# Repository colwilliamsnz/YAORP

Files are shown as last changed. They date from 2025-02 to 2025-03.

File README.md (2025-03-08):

# YAORP (Yet Another Open Reflow Plate)

## Status:

Tested an initial v1.0 board. Various improvements and bug fixes applied to produce rev 1.2 (build pending). Basic PoC firmware written.

## Introduction:

A design for a solder reflow plate for SMD rework using commonly available aluminium 240V AC 400W PTC (positive temperature coefficient) heating plate from AliExpress.

PTC temperature is determined using an infrared thermometer (MLX90614). The PTC is driven by an SSR (solid state relay) using PWM (pulse width modulation), and controlled by a PID (proportional integral derivative).

An ESP32 S3 Wroom 1 module forms the heart of the design and firmware is written in C++ for Arduino IDE. 

Two PCBs have been designed using KiCAD 9. The main controller board (board 1) and a cooling plate/heat dissipator (board 2).

## Project Goals:

- Enhance my knowledge of electronics. 
- Learn KiCad.
- Make the move away from hand soldered components.
- Build a useful addition to my lab.
- Make it as professional as possible.

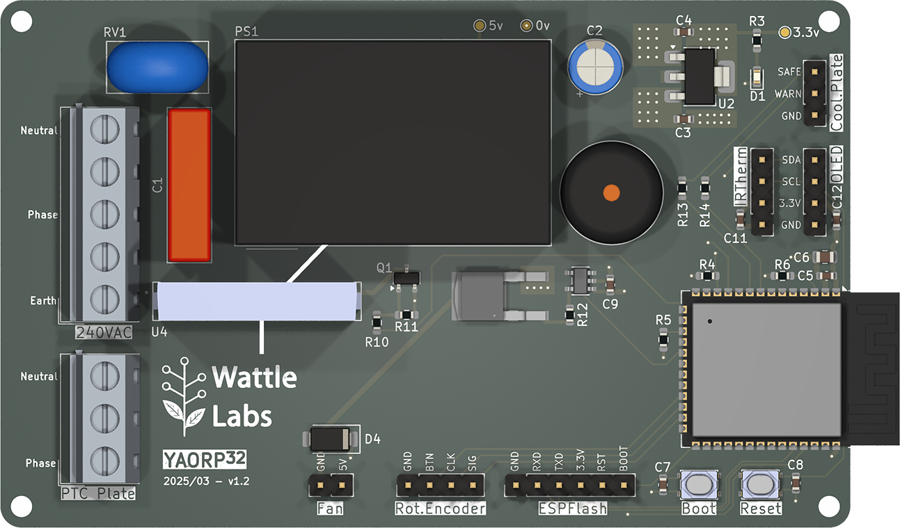
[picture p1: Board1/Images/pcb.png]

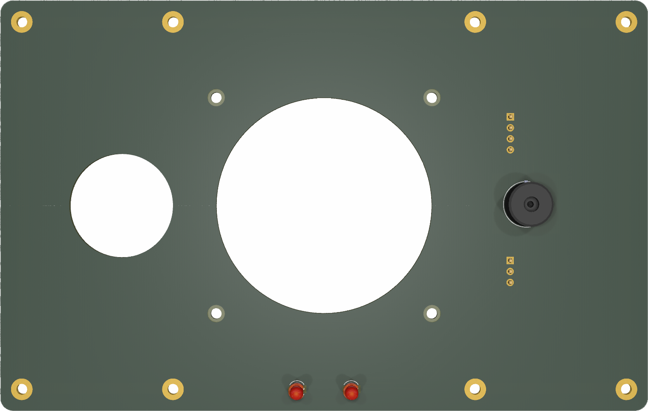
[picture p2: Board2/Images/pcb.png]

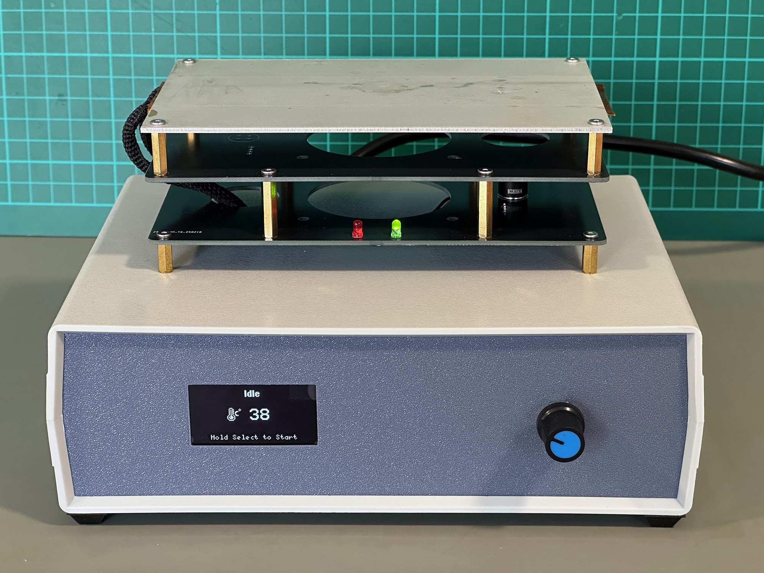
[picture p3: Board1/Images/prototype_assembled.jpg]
Prototype

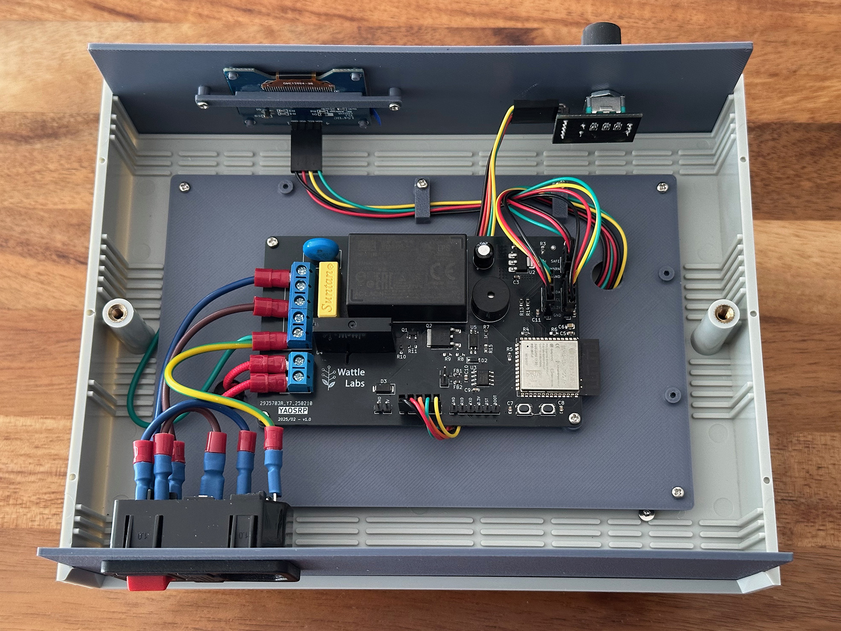
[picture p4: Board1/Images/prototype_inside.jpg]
Prototype


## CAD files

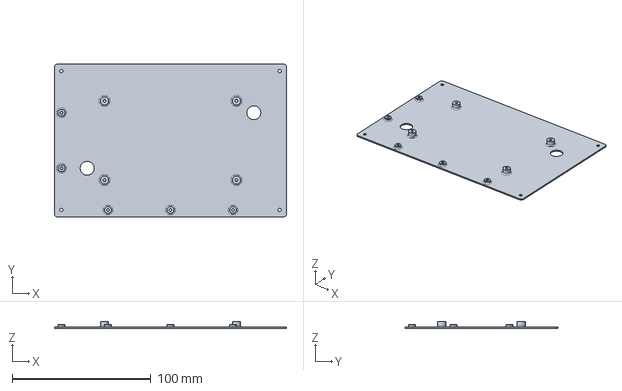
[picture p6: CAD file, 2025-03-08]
Board1/CAD/Case Mount.FCStd
167.0 x 110.0 x 5.00 mm

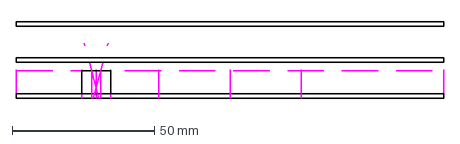
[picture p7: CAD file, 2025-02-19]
Board2/CAD/Cooling Plate 30deg Calc.dxf
150.0 x 26.8 mm

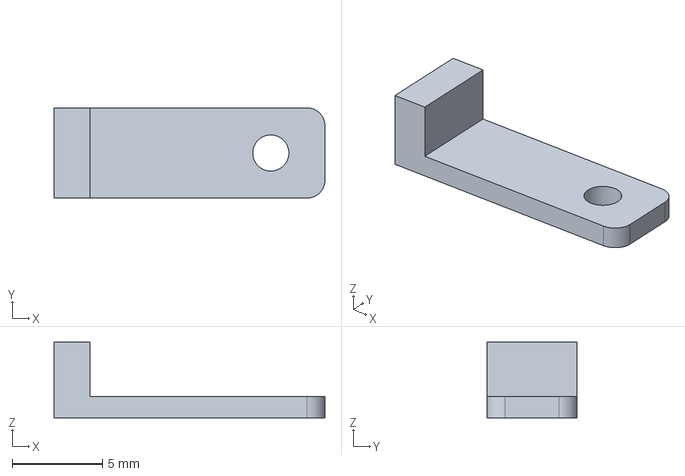
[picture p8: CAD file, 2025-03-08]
Board1/CAD/Cable Clips.FCStd
15.0 x 5.00 x 4.20 mm

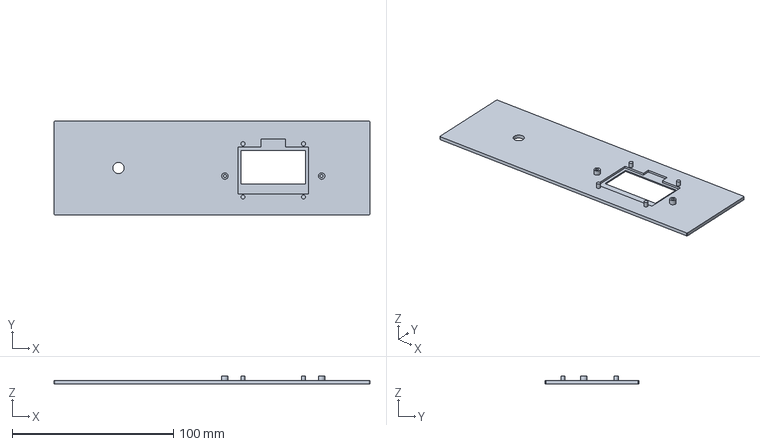
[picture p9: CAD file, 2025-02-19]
Board1/CAD/Front Panel.FCStd
196.0 x 58.0 x 5.15 mm

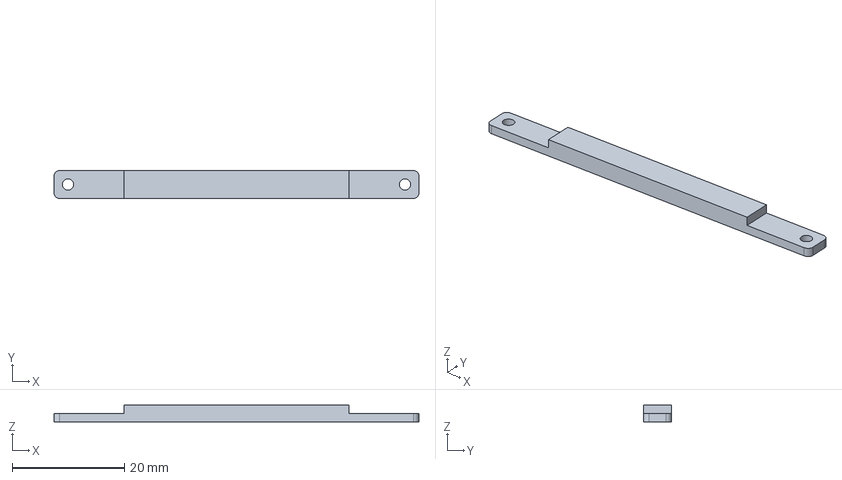
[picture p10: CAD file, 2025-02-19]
Board1/CAD/Screen Backplate.FCStd
65.0 x 5.00 x 3.00 mm

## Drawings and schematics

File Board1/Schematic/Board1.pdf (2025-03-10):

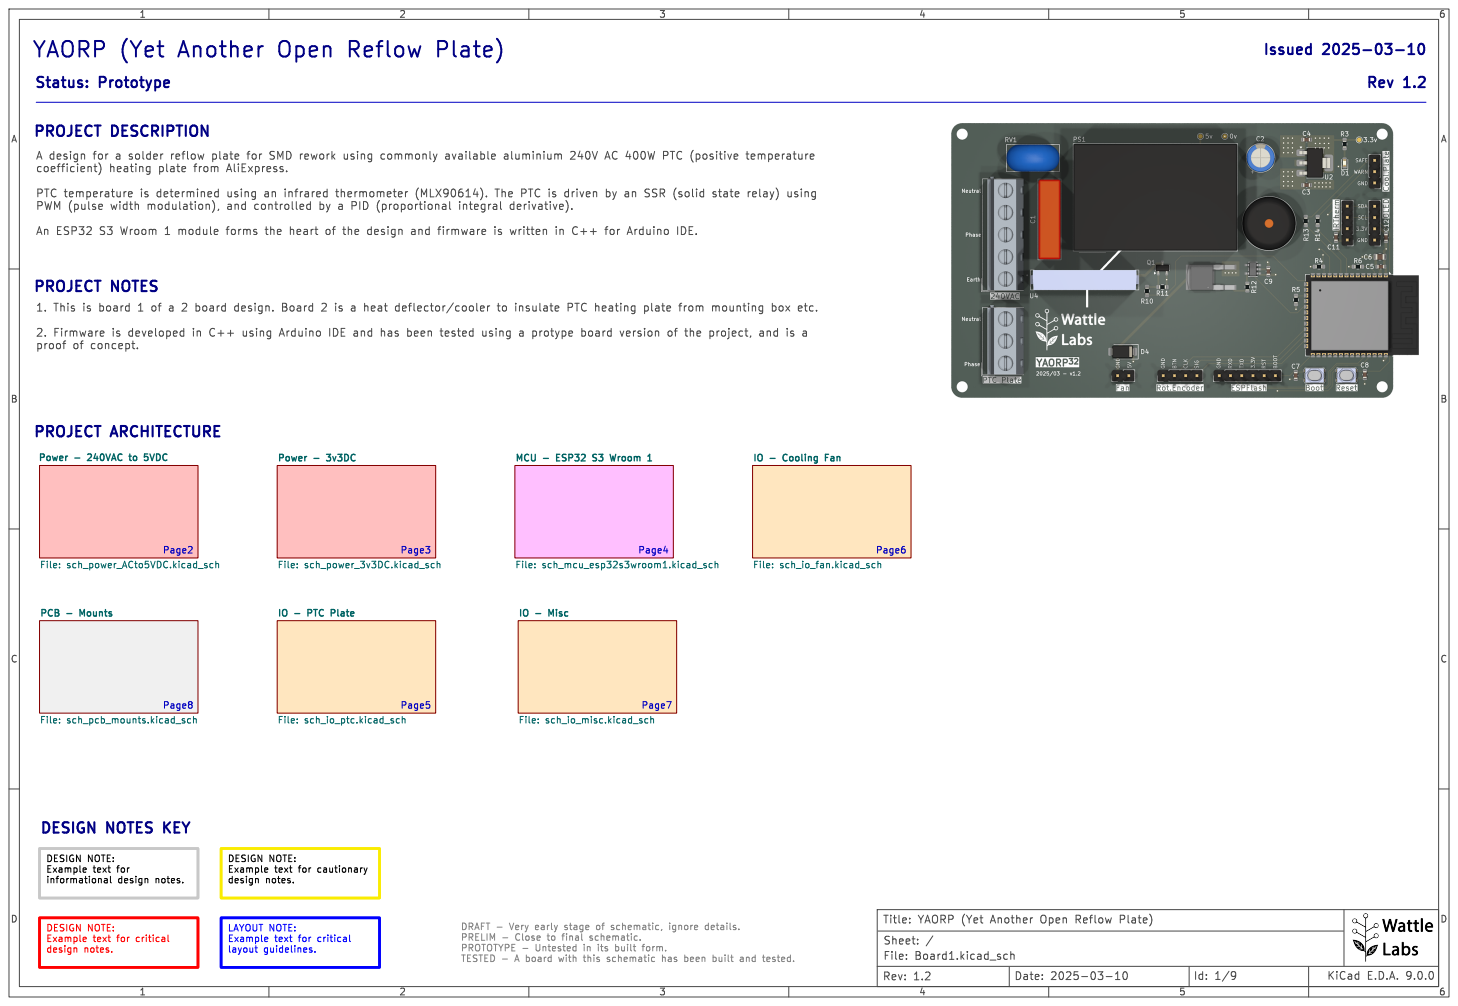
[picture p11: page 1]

IO - Misc File: sch_io_misc.kicad_sch Power - 240VAC to 5VDC

IO - PTC Plate File: sch_io_ptc.kicad_sch PCB - Mounts File: sch_pcb_mounts.kicad_sch

design notes. DESIGN NOTE: Example text for

layout guidelines. DESIGN NOTE: Example text for cautionary

LAYOUT NOTE: Example text for critical

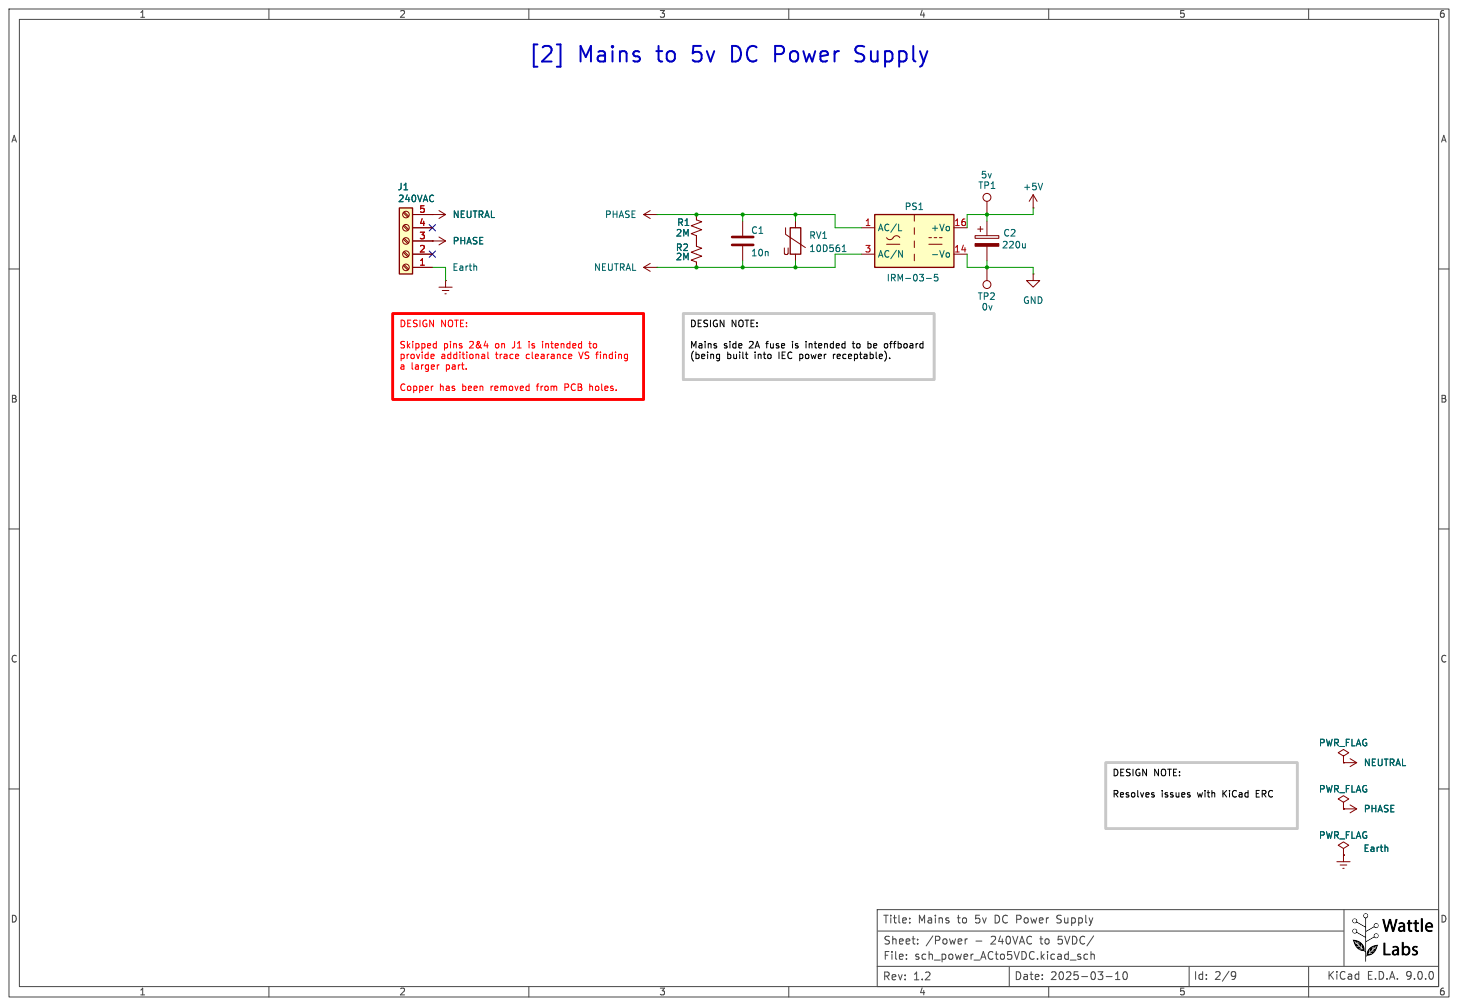
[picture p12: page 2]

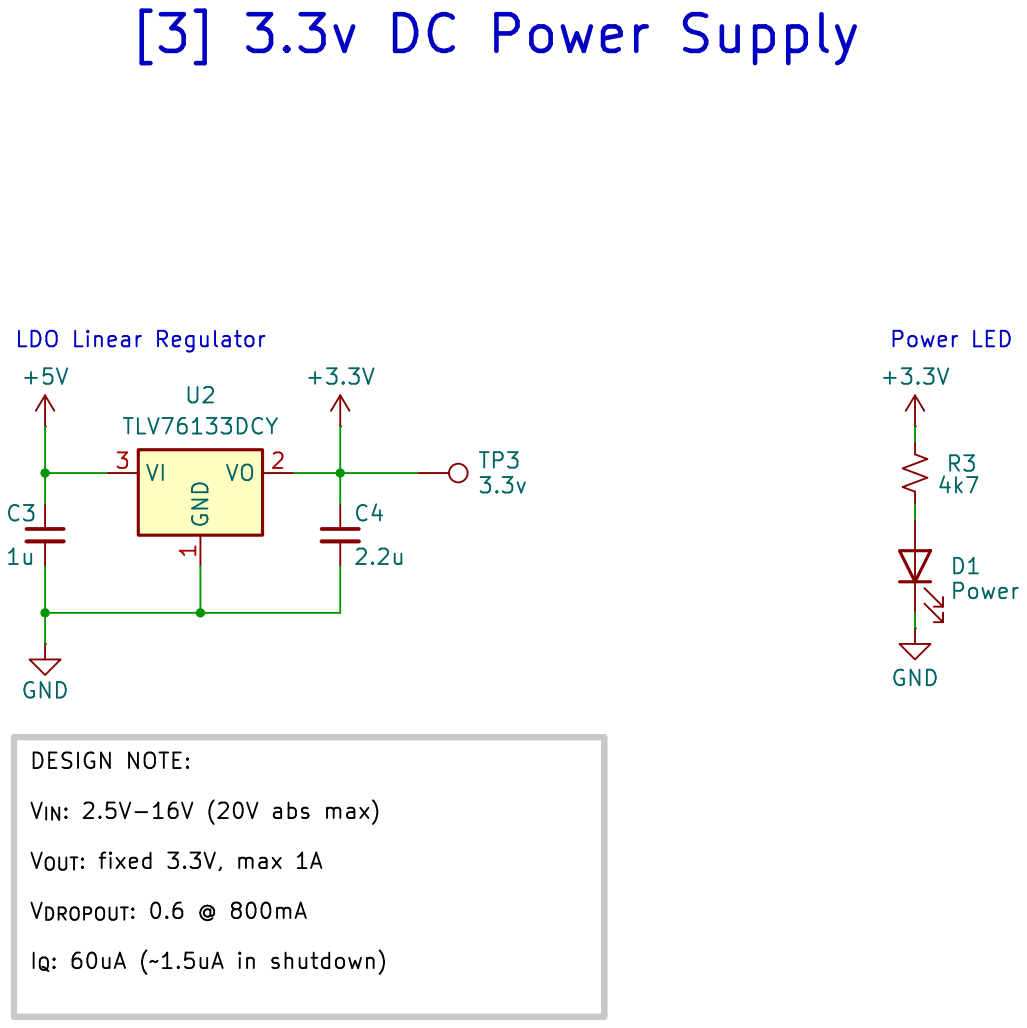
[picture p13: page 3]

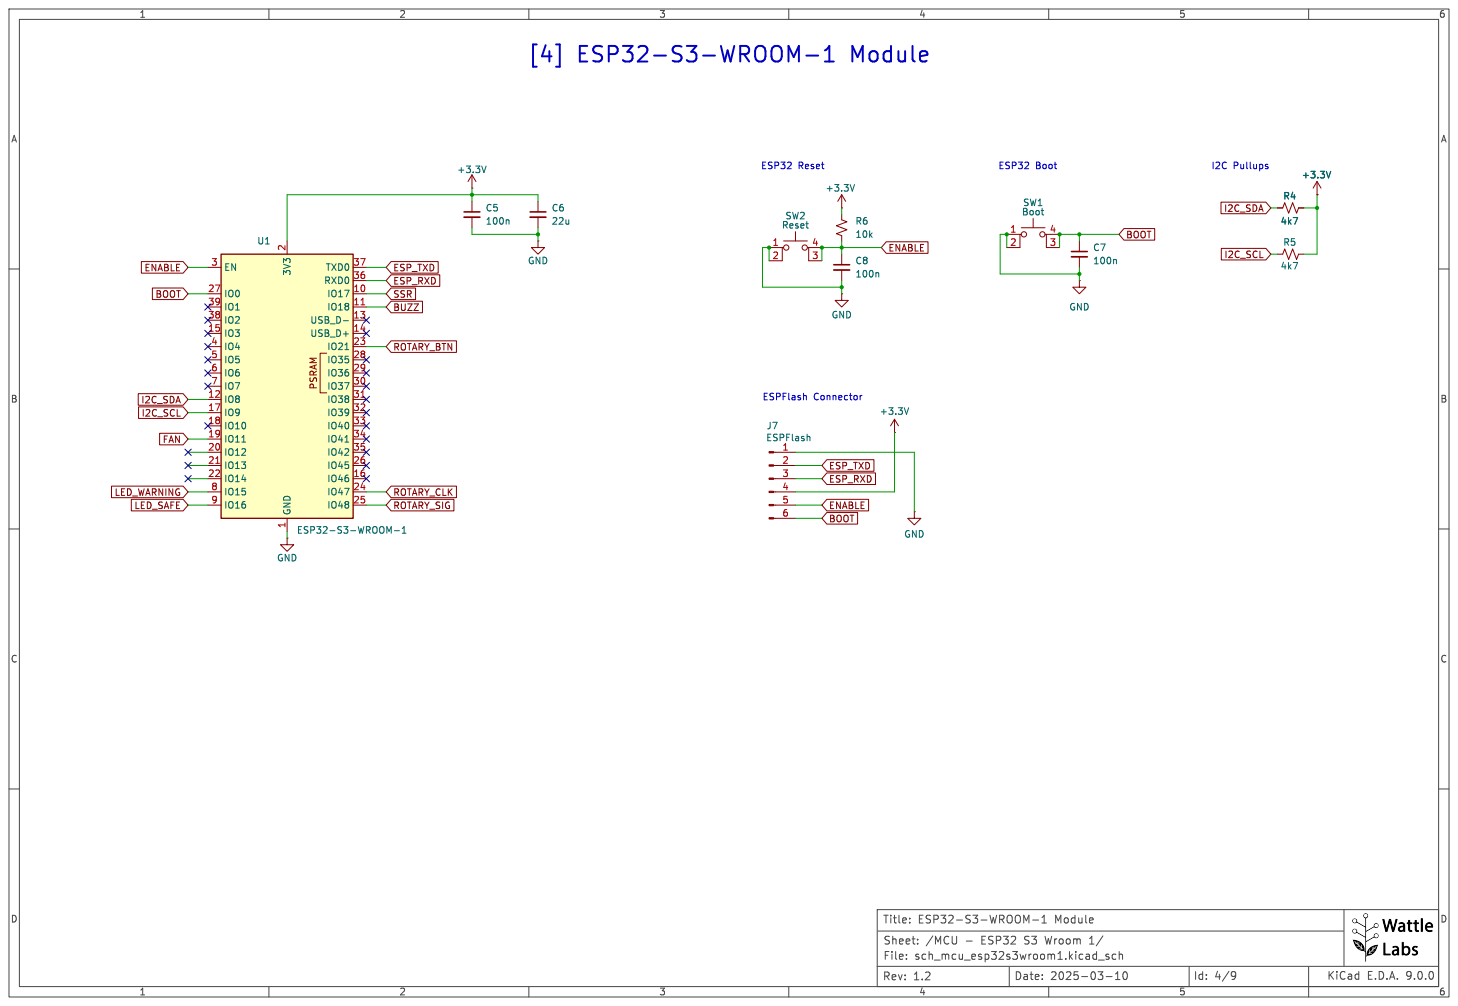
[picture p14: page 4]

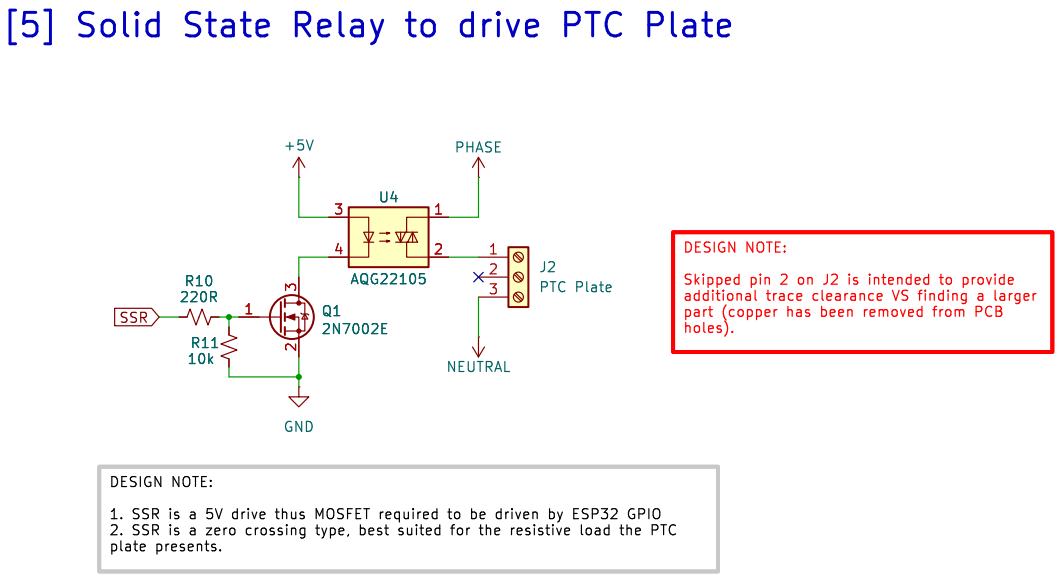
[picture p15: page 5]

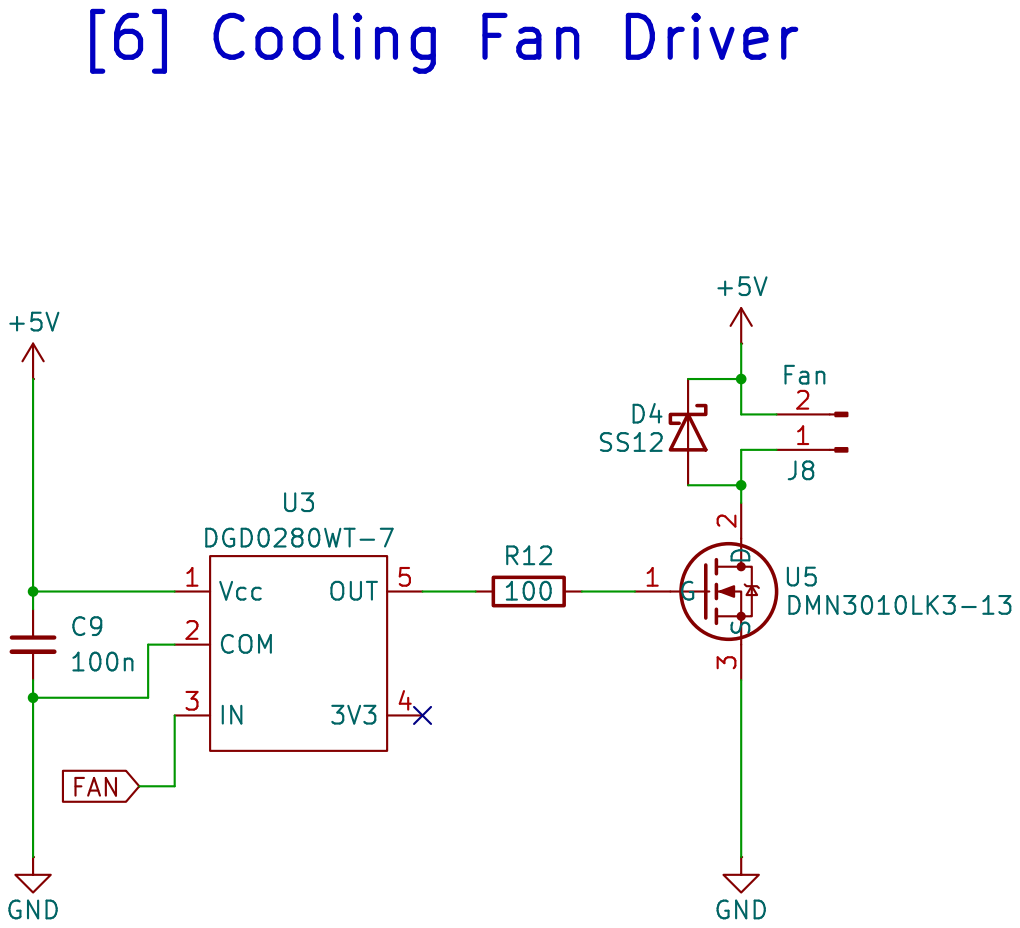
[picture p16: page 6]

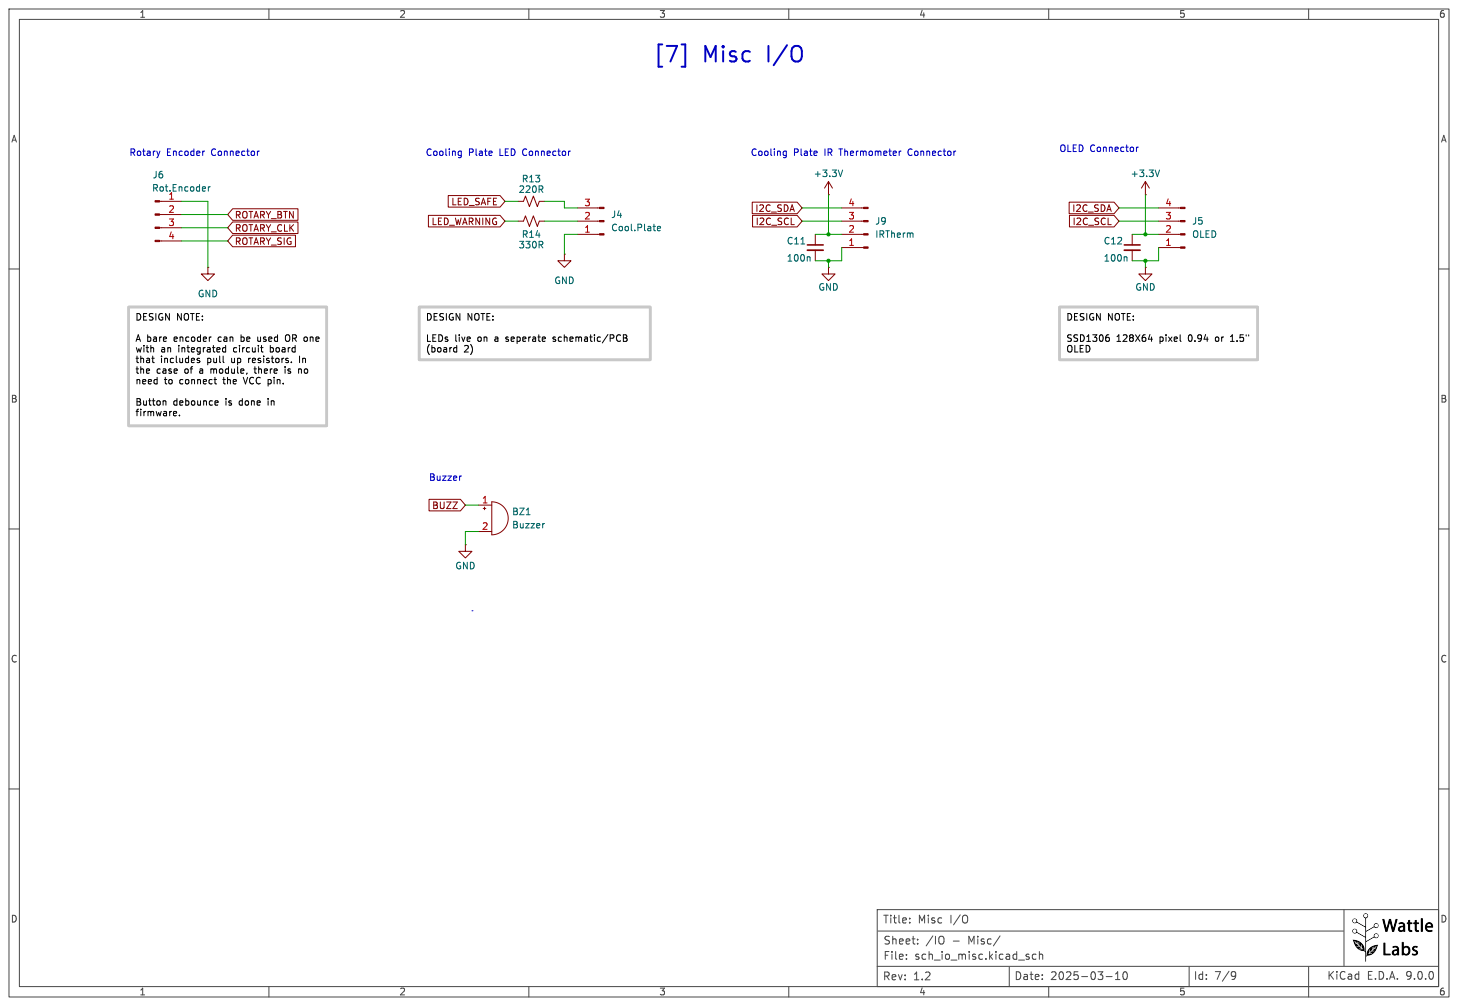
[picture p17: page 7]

DESIGN NOTE: LEDs live on a seperate schematic/PCB

the case of a module, there is no
need to connect the VCC pin. Button debounce is done in

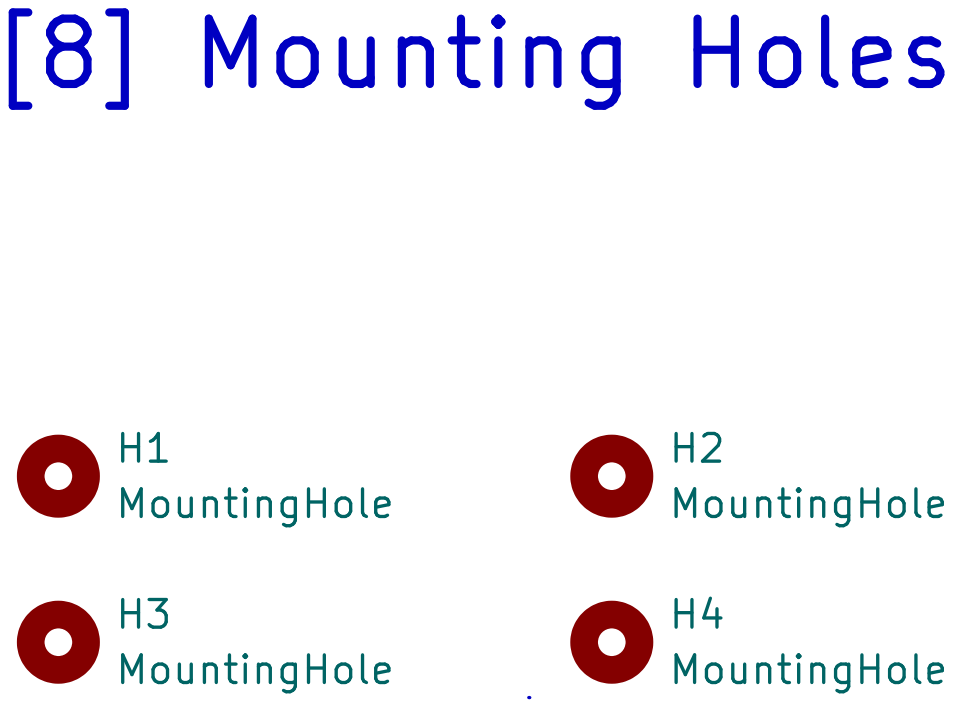
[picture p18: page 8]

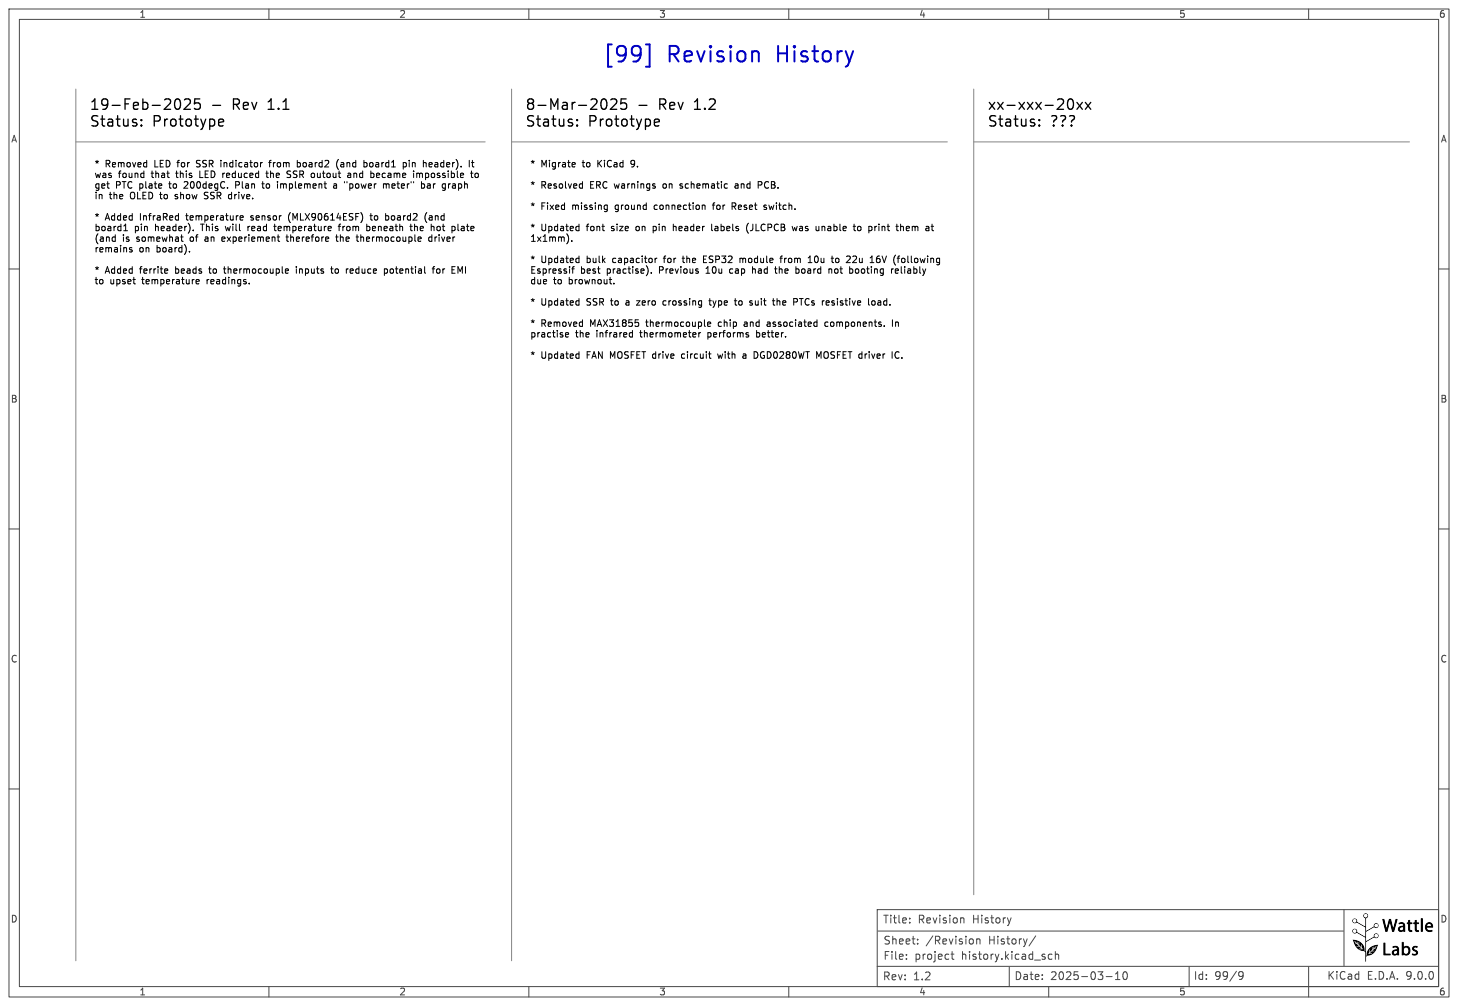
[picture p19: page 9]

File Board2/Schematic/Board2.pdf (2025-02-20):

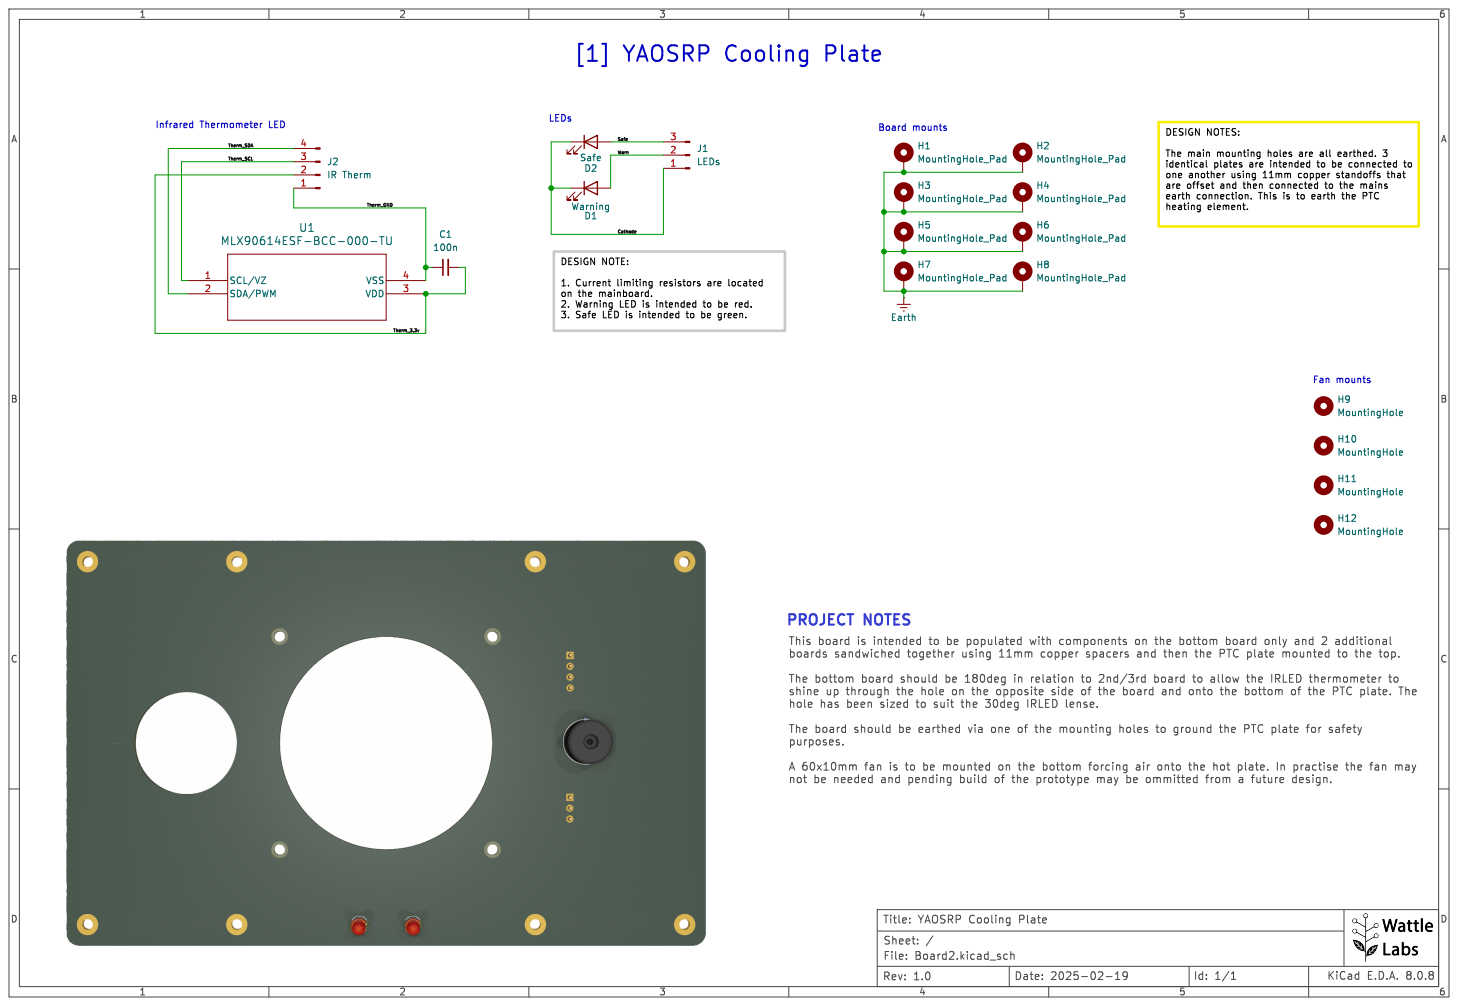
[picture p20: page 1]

shine up through the hole on the opposite side of the board and onto the bottom of the PTC plate. The

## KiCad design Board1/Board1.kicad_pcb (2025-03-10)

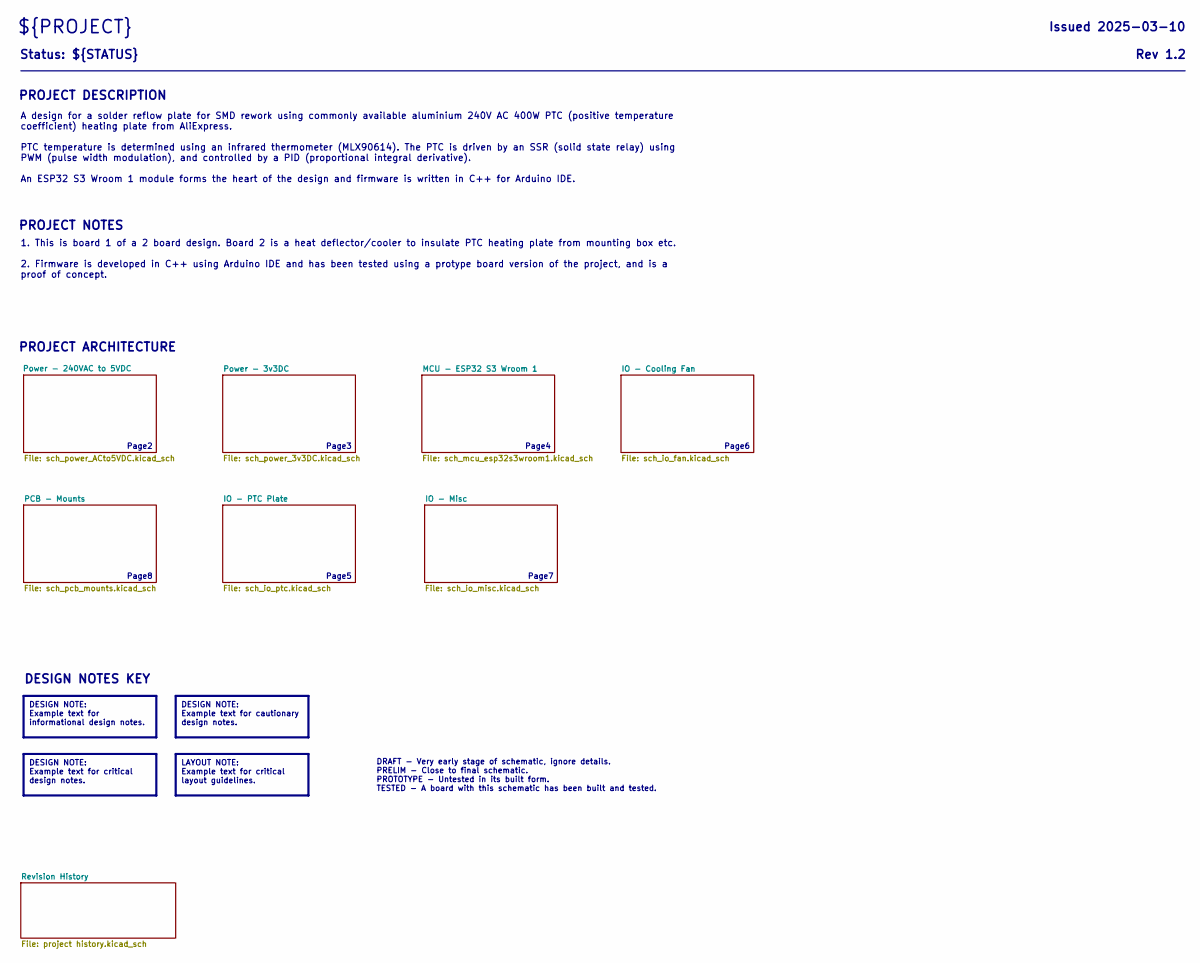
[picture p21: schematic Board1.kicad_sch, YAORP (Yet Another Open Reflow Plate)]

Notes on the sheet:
Page3
PROJECT DESCRIPTION
PROJECT NOTES
Page6
Page7
DESIGN NOTES KEY
PROJECT ARCHITECTURE
Page2
Page8
Page4
Page5
DESIGN NOTE: Example text for critical design notes.
DESIGN NOTE: Example text for informational design notes.
DESIGN NOTE: Example text for cautionary design notes.
Status: ${STATUS}
DRAFT - Very early stage of schematic, ignore details. PRELIM - Close to final schematic. PROTOTYPE - Untested in its built form. TESTED - A board with this schematic has been built and tested.
1. This is board 1 of a 2 board design. Board 2 is a heat deflector/cooler to insulate PTC heating plate from mounting box etc. 2. Firmware is developed in C++ using Arduino IDE and has been tested using a protype board version of the project, and is a proof of concept.
Rev ${REVISION}
A design for a solder reflow plate for SMD rework using commonly available aluminium 240V AC 400W PTC (positive temperature coefficient) heating plate from AliExpress. PTC temperature is determined using an infrared thermometer (MLX90614). The PTC is driven by an SSR (solid state relay) using PWM (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
${PROJECT}
LAYOUT NOTE: Example text for critical layout guidelines.
Issued ${ISSUE_DATE}

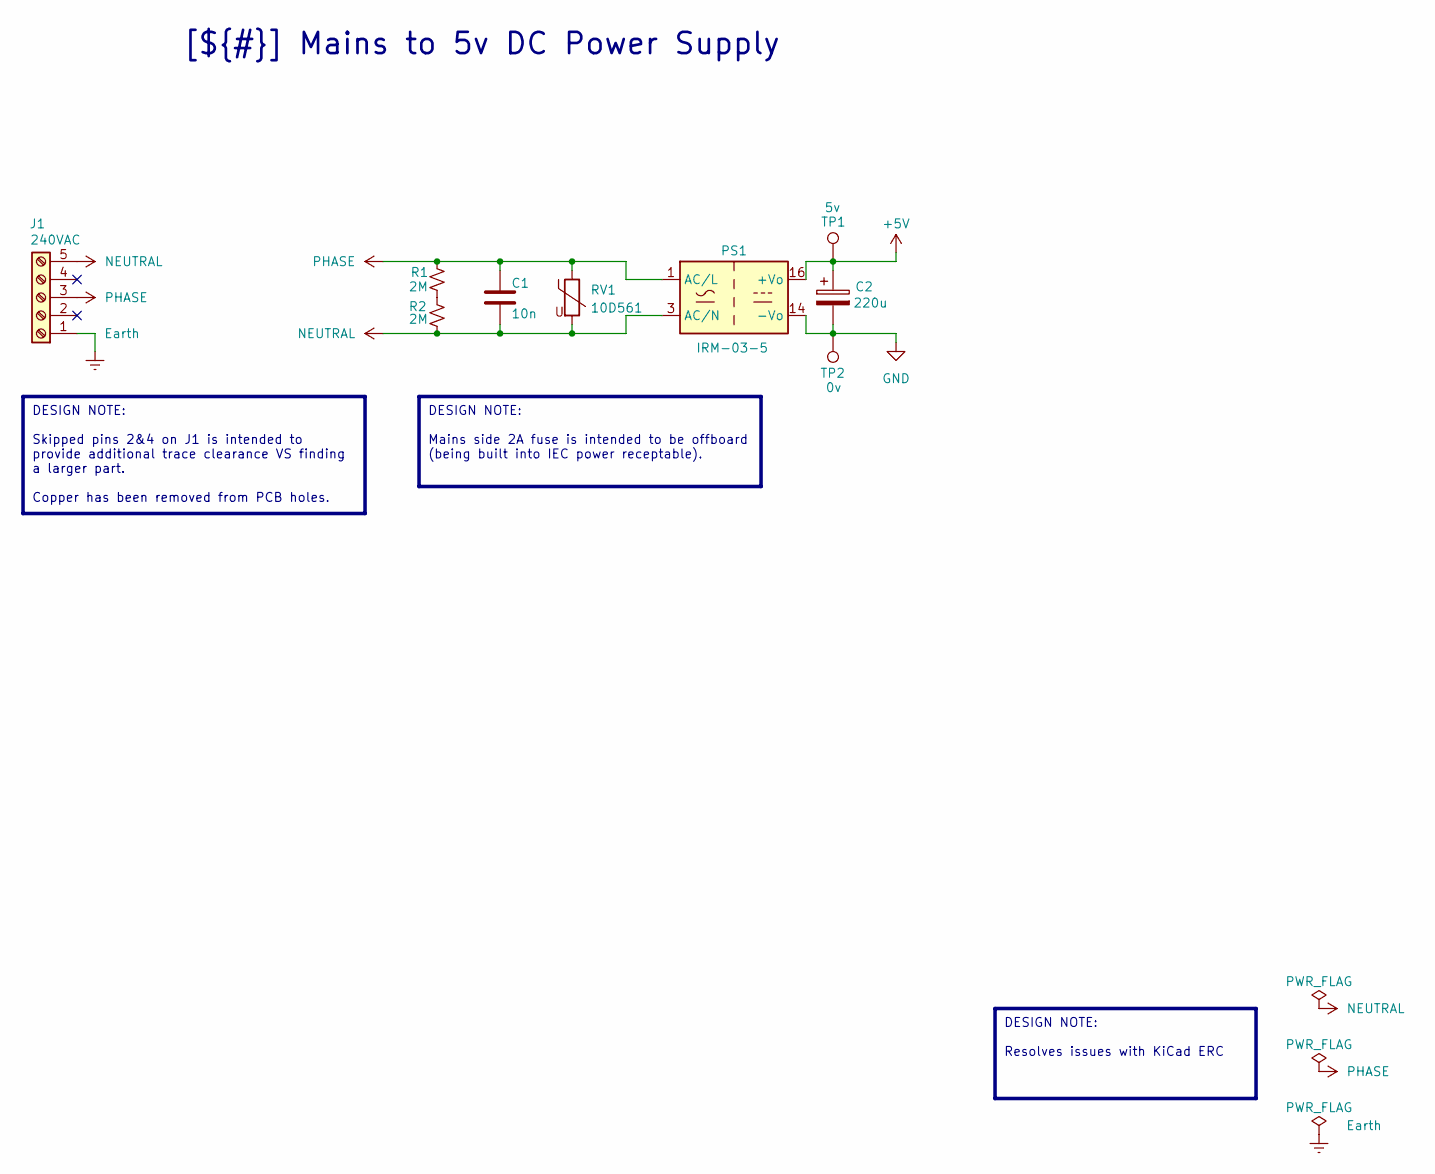
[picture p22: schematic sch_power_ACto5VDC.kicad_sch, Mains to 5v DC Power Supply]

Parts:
C1: 10n; C_Rect_L18.0mm_W5.0mm_P15.00mm_FKS3_FKP3; Digikey_PN BFC233841103-ND
C2: 220u; CP_Radial_D6.3mm_P2.50mm
J1: 240VAC; Altech_AK100_1x05_P5.00mm
PS1: IRM-03-5; Converter_ACDC_MeanWell_IRM-03-xx_THT; Digikey_PN 1866-3020-ND
R1, R2: 2M; R_2010_5025Metric_Pad1.40x2.65mm_HandSolder; Digikey_PN 2019-HV732HTTE2004FCT-ND
RV1: 10D561; RV_Disc_D12mm_W6.1mm_P7.5mm; Digikey_PN 118-MOV-10D561K-ND
TP1: 5v; TestPoint_Pad_D1.0mm
TP2: 0v; TestPoint_Pad_D1.0mm

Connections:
+5V: C2.1, PS1.16 (+Vo), TP1.1; also elsewhere on the board
GND: C2.2, PS1.14 (-Vo), TP2.1; also elsewhere on the board
NEUTRAL: C1.2, J1.5, PS1.3 (AC/N), R2.2, RV1.2; also elsewhere on the board
unnamed: R1.2, R2.1
PHASE: C1.1, J1.3, PS1.1 (AC/L), R1.1, RV1.1; also elsewhere on the board

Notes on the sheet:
DESIGN NOTE: Skipped pins 2&4 on J1 is intended to provide additional trace clearance VS finding a larger part. Copper has been removed from PCB holes.
DESIGN NOTE: Mains side 2A fuse is intended to be offboard (being built into IEC power receptable).
[${#}] ${TITLE}
DESIGN NOTE: Resolves issues with KiCad ERC

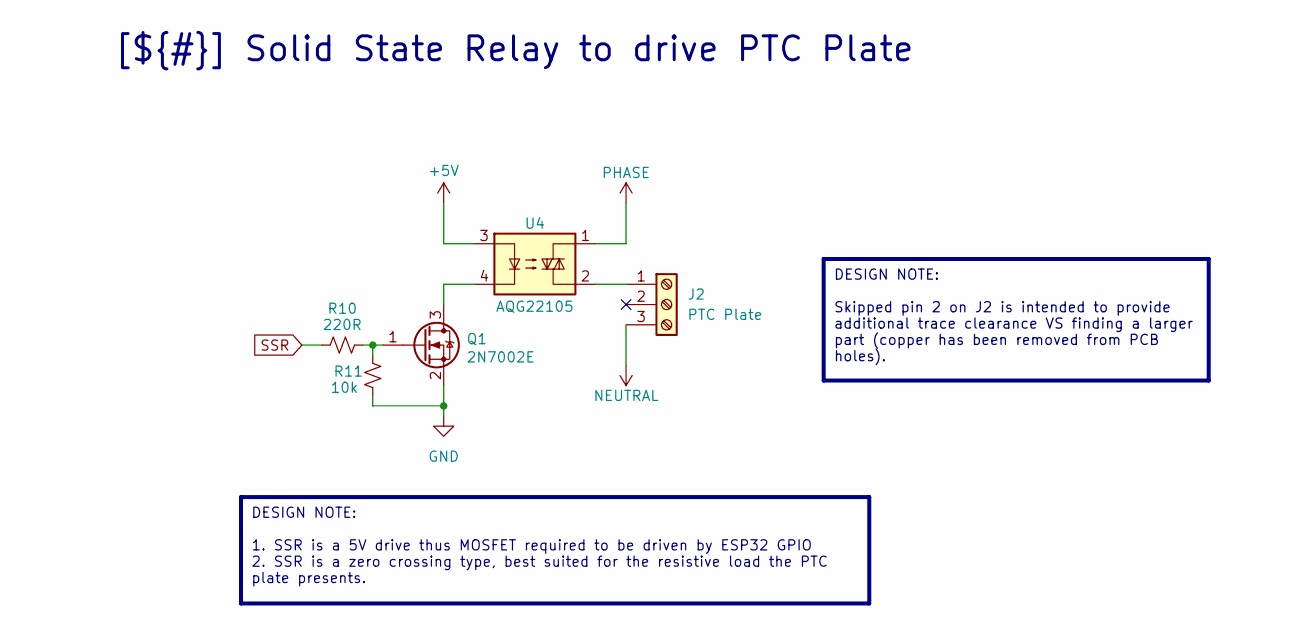
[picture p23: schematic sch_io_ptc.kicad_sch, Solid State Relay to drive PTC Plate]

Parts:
J2: PTC Plate; Altech_AK100_1x03_P5.00mm
Q1: 2N7002E; SOT-23; Digikey_PN 2N7002E-ND
R10: 220R; R_0603_1608Metric_Pad0.98x0.95mm_HandSolder; Digikey_PN 541-10440-1-ND
R11: 10k; R_0603_1608Metric_Pad0.98x0.95mm_HandSolder; Digikey_PN 541-10.0KHCT-ND
U4: AQG22105; SSR_AQG22105; Digikey_PN 255-2102-5-ND

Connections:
+5V: U4.3; also elsewhere on the board
GND: Q1.2 (S), R11.2; also elsewhere on the board
NEUTRAL: J2.3; also elsewhere on the board
unnamed: J2.1, U4.2
unnamed: Q1.3 (D), U4.4
unnamed: Q1.1 (G), R10.1, R11.1
PHASE: U4.1; also elsewhere on the board
SSR: R10.2; also elsewhere on the board

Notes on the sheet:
DESIGN NOTE: 1. SSR is a 5V drive thus MOSFET required to be driven by ESP32 GPIO 2. SSR is a zero crossing type, best suited for the resistive load the PTC plate presents.
[${#}] ${TITLE}
DESIGN NOTE: Skipped pin 2 on J2 is intended to provide additional trace clearance VS finding a larger part (copper has been removed from PCB holes).

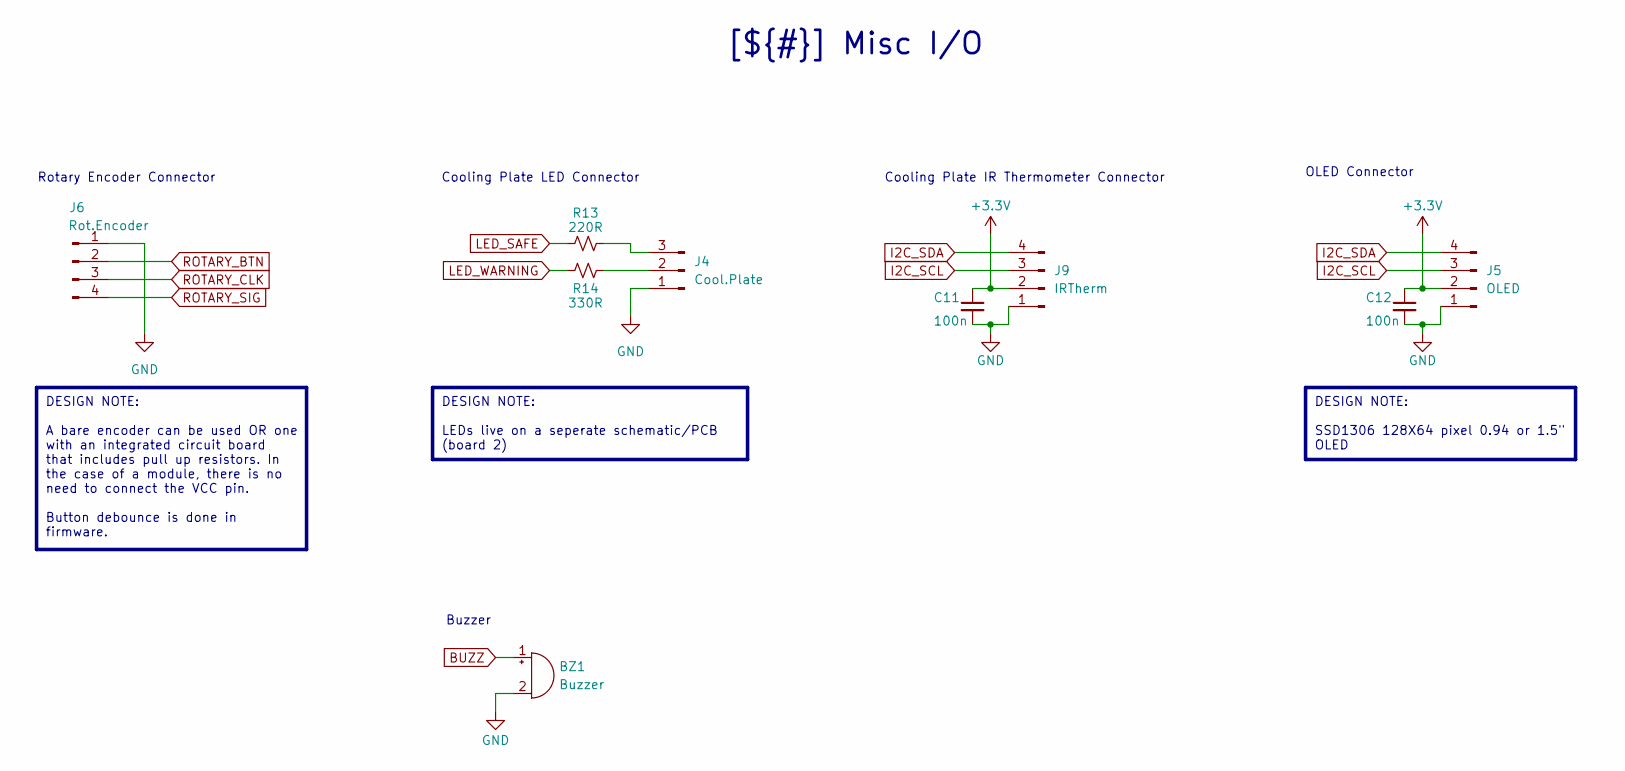
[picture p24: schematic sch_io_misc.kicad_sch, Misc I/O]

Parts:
BZ1: Buzzer; Buzzer_12x9.5RM7.6; Digikey_PN 668-1470-ND
C11, C12: 100n; C_0603_1608Metric; Digikey_PN 399-C0603C104K4RACTUCT-ND
J4: Cool.Plate; PinHeader_1x03_P2.54mm_Vertical
J5: OLED; PinHeader_1x04_P2.54mm_Vertical
J6: Rot.Encoder; PinHeader_1x04_P2.54mm_Vertical
J9: IRTherm; PinHeader_1x04_P2.54mm_Vertical
R13: 220R; R_0603_1608Metric_Pad0.98x0.95mm_HandSolder; Digikey_PN 541-10440-1-ND
R14: 330R; R_0603_1608Metric_Pad0.98x0.95mm_HandSolder; Digikey_PN 541-10456-1-ND

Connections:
+3.3V: C11.1, C12.1, J5.2, J9.2; also elsewhere on the board
BUZZ: BZ1.1 (+); also elsewhere on the board
GND: BZ1.2 (-), C11.2, C12.2, J4.1, J5.1, J6.1, J9.1; also elsewhere on the board
I2C_SCL: J5.3, J9.3; also elsewhere on the board
I2C_SDA: J5.4, J9.4; also elsewhere on the board
LED_SAFE: R13.2; also elsewhere on the board
LED_WARNING: R14.2; also elsewhere on the board
unnamed: J4.2, R14.1
unnamed: J4.3, R13.1
ROTARY_BTN: J6.2; also elsewhere on the board
ROTARY_CLK: J6.3; also elsewhere on the board
ROTARY_SIG: J6.4; also elsewhere on the board

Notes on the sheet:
OLED Connector
Rotary Encoder Connector
Cooling Plate LED Connector
Cooling Plate IR Thermometer Connector
Buzzer
DESIGN NOTE: LEDs live on a seperate schematic/PCB (board 2)
DESIGN NOTE: SSD1306 128X64 pixel 0.94 or 1.5" OLED
DESIGN NOTE: A bare encoder can be used OR one with an integrated circuit board that includes pull up resistors. In the case of a module, there is no need to connect the VCC pin. Button debounce is done in firmware.
[${#}] ${TITLE}

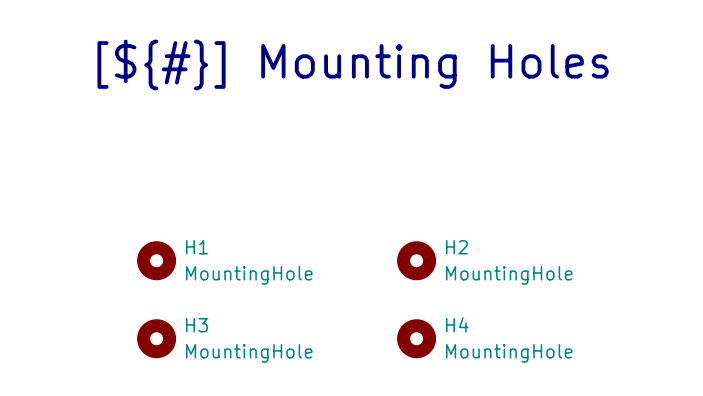
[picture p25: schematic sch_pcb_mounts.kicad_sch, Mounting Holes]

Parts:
H1, H2, H3, H4: MountingHole; MountingHole_2.5mm

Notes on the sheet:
[${#}] ${TITLE}

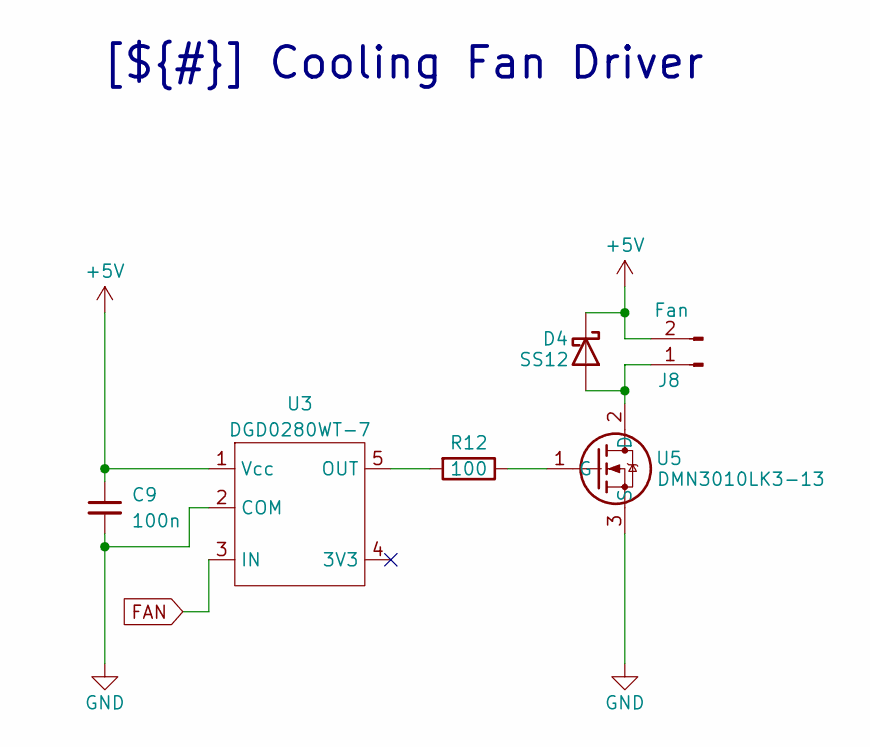
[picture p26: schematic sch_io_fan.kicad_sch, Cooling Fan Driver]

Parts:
C9: 100n; C_0603_1608Metric; Digikey_PN 399-C0603C104K4RACTUCT-ND
D4: SS12; D_SMA; Digikey_PN SS12FSCT-ND
J8: Fan; PinHeader_1x02_P2.54mm_Vertical
R12: 100; R_0603_1608Metric; Digikey_PN 541-3951-1-ND
U3: DGD0280WT-7; SOT23-5_INF; Digikey_PN 31-DGD0280WT-7CT-ND
U5: DMN3010LK3-13; TO252-3L_DIO; Digikey_PN 31-DMN3010LK3-13CT-ND

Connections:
+5V: C9.1, D4.1 (K), J8.2, U3.1 (Vcc); also elsewhere on the board
FAN: U3.3 (IN); also elsewhere on the board
GND: C9.2, U3.2 (COM), U5.3 (S); also elsewhere on the board
unnamed: D4.2 (A), J8.1, U5.2 (D)
unnamed: R12.2, U3.5 (OUT)
unnamed: R12.1, U5.1 (G)

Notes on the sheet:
[${#}] ${TITLE}

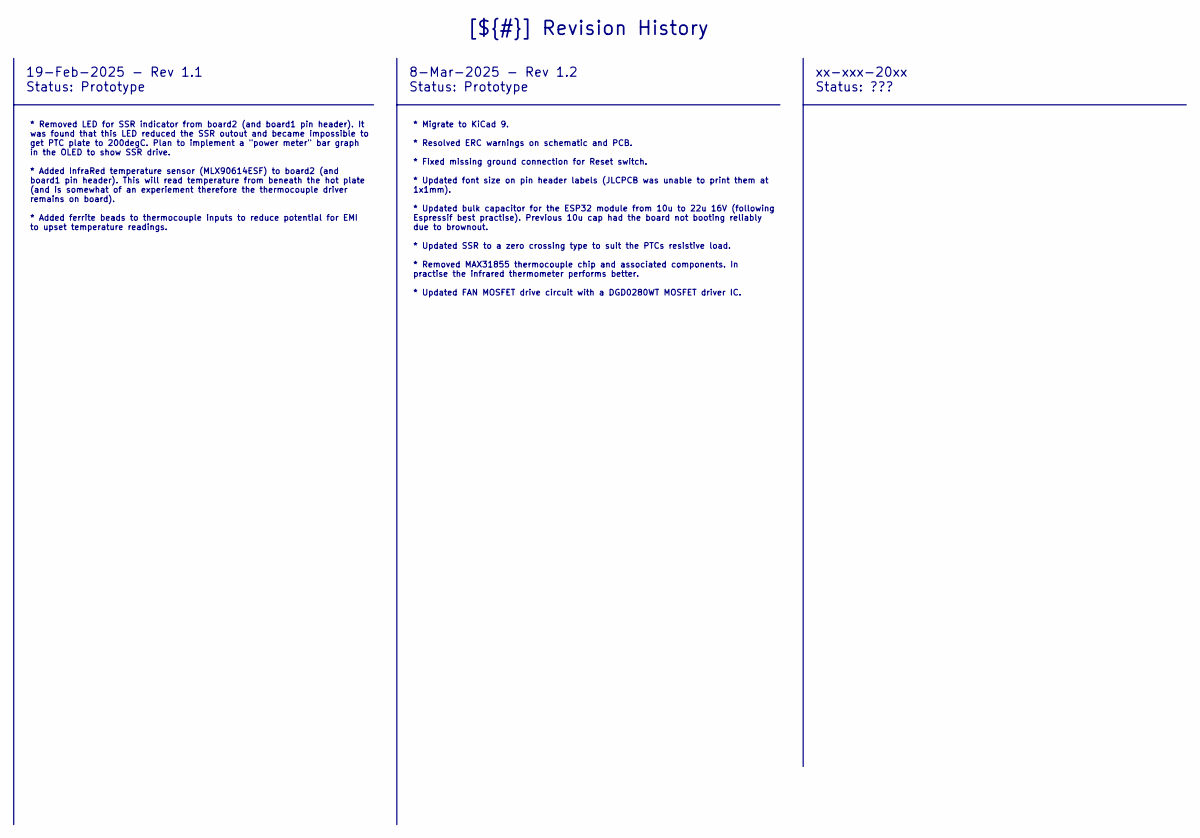
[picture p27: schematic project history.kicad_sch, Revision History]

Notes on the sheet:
19-Feb-2025 - Rev 1.1 Status: Prototype
8-Mar-2025 - Rev 1.2 Status: Prototype
xx-xxx-20xx Status: ???
* Removed LED for SSR indicator from board2 (and board1 pin header). It was found that this LED reduced the SSR outout and became impossible to get PTC plate to 200degC. Plan to implement a "power meter" bar graph in the OLED to show SSR drive. * Added InfraRed temperature sensor (MLX90614ESF) to b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
[${#}] ${TITLE}
* Migrate to KiCad 9. * Resolved ERC warnings on schematic and PCB. * Fixed missing ground connection for Reset switch. * Updated font size on pin header labels (JLCPCB was unable to print them at 1x1mm). * Updated bulk capacitor for the ESP32 module from 10u to 22u 16V (following Espressif best pr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

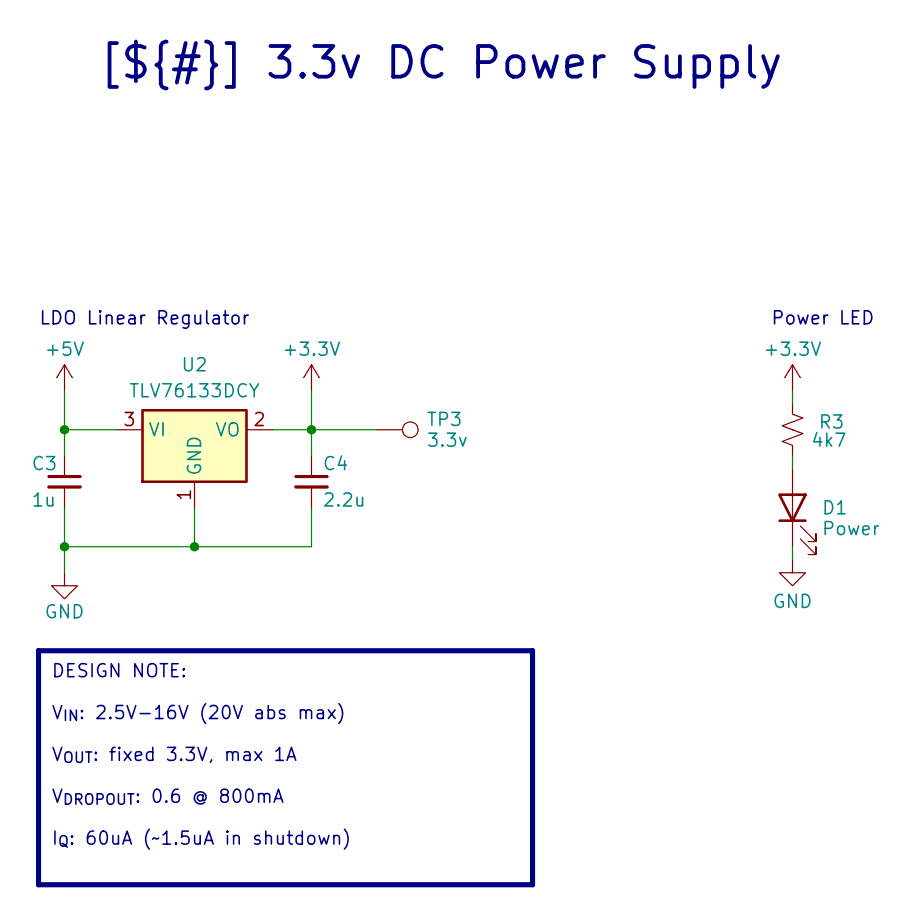
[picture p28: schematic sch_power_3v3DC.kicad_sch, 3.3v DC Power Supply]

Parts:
C3: 1u; C_0603_1608Metric; Digikey_PN 1276-1019-1-ND
C4: 2.2u; C_0603_1608Metric; Digikey_PN 1276-1040-1-ND
D1: Power; LED_0603_1608Metric; Digikey_PN 732-4978-1-ND
R3: 4k7; R_0603_1608Metric_Pad0.98x0.95mm_HandSolder; Digikey_PN 541-3993-1-ND
TP3: 3.3v; TestPoint_Pad_D1.0mm
U2: TLV76133DCY; SOT-223-3_TabPin2; Digikey_PN 296-TLV76133DCYRCT-ND

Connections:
+3.3V: C4.1, R3.2, TP3.1, U2.2 (VO); also elsewhere on the board
+5V: C3.1, U2.3 (VI); also elsewhere on the board
GND: C3.2, C4.2, D1.1 (K), U2.1 (GND); also elsewhere on the board
unnamed: D1.2 (A), R3.1

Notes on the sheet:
LDO Linear Regulator
Power LED
DESIGN NOTE: V_{IN}: 2.5V-16V (20V abs max) V_{OUT}: fixed 3.3V, max 1A V_{DROPOUT}: 0.6 @ 800mA I_{Q}: 60uA (~1.5uA in shutdown)
[${#}] ${TITLE}

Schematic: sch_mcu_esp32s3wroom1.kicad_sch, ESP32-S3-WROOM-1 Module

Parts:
C5, C7, C8: 100n; C_0603_1608Metric; Digikey_PN 399-C0603C104K4RACTUCT-ND
C6: 22u; C_0805_2012Metric; Digikey_PN 1276-2909-1-ND
J7: ESPFlash; PinHeader_1x06_P2.54mm_Vertical
R4, R5: 4k7; R_0603_1608Metric_Pad0.98x0.95mm_HandSolder; Digikey_PN 541-3993-1-ND
R6: 10k; R_0603_1608Metric_Pad0.98x0.95mm_HandSolder; Digikey_PN 541-10.0KHCT-ND
SW1: Boot; SW_SPST_PTS810; Digikey_PN CKN10878CT-ND
SW2: Reset; SW_SPST_PTS810; Digikey_PN CKN10878CT-ND
U1: ESP32-S3-WROOM-1; Digikey_PN 1965-ESP32-S3-WROOM-1-N4R2CT-ND

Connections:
+3.3V: C5.1, C6.1, J7.4, R4.1, R5.1, R6.2, U1.2 (3V3); also elsewhere on the board
BOOT: C7.1, J7.6, SW1.3 (K), SW1.4 (A), U1.27 (IO0)
BUZZ: U1.11 (IO18); also elsewhere on the board
ENABLE: C8.1, J7.5, R6.1, SW2.3 (K), SW2.4 (A), U1.3 (EN)
ESP_RXD: J7.3, U1.36 (RXD0)
ESP_TXD: J7.2, U1.37 (TXD0)
FAN: U1.19 (IO11); also elsewhere on the board
GND: C5.2, C6.2, C7.2, C8.2, J7.1, SW1.1, SW1.2, SW2.1, SW2.2, U1.1 (GND), U1.40 (GND), U1.41 (GND); also elsewhere on the board
I2C_SCL: R5.2, U1.17 (IO9); also elsewhere on the board
I2C_SDA: R4.2, U1.12 (IO8); also elsewhere on the board
LED_SAFE: U1.9 (IO16); also elsewhere on the board
LED_WARNING: U1.8 (IO15); also elsewhere on the board
ROTARY_BTN: U1.23 (IO21); also elsewhere on the board
ROTARY_CLK: U1.24 (IO47); also elsewhere on the board
ROTARY_SIG: U1.25 (IO48); also elsewhere on the board
SSR: U1.10 (IO17); also elsewhere on the board

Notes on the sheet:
I2C Pullups
ESP32 Reset
ESP32 Boot
ESPFlash Connector
[${#}] ${TITLE}

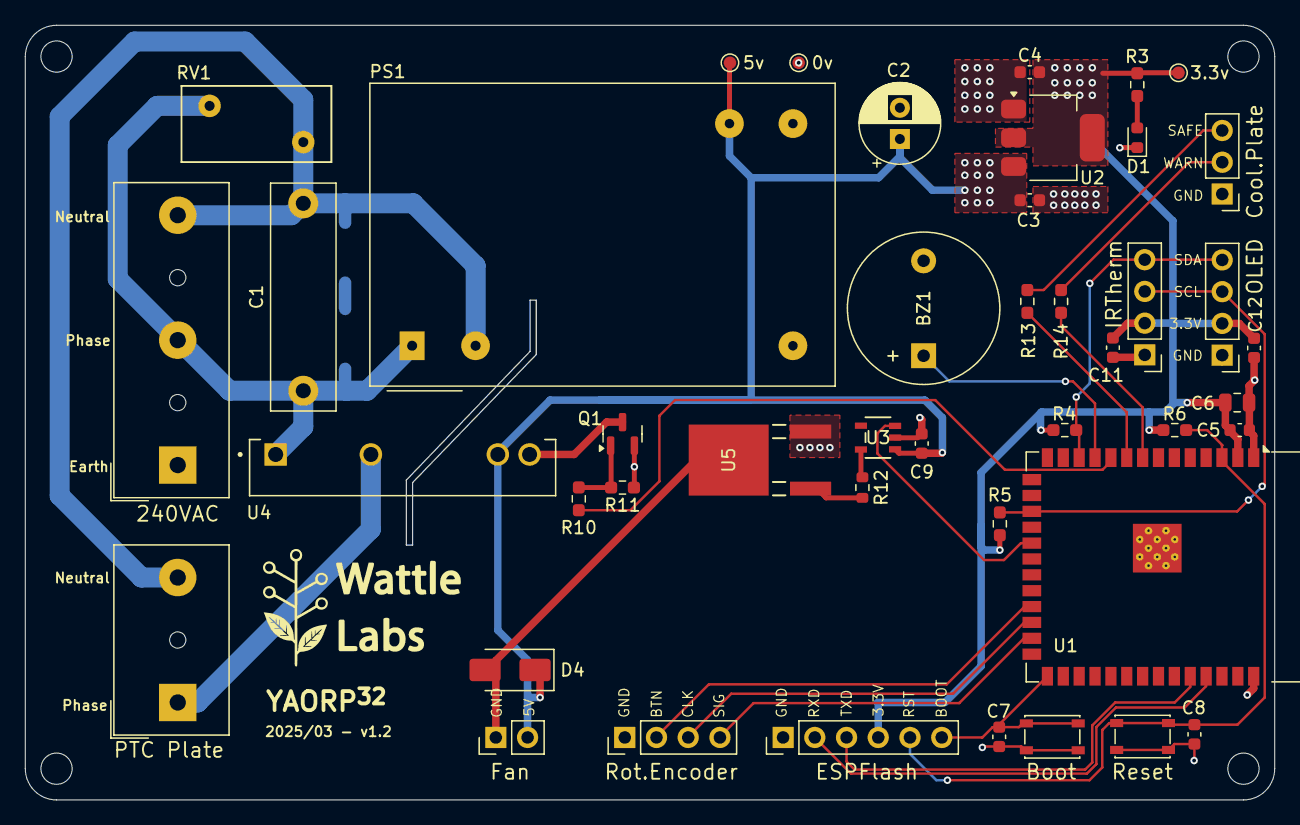
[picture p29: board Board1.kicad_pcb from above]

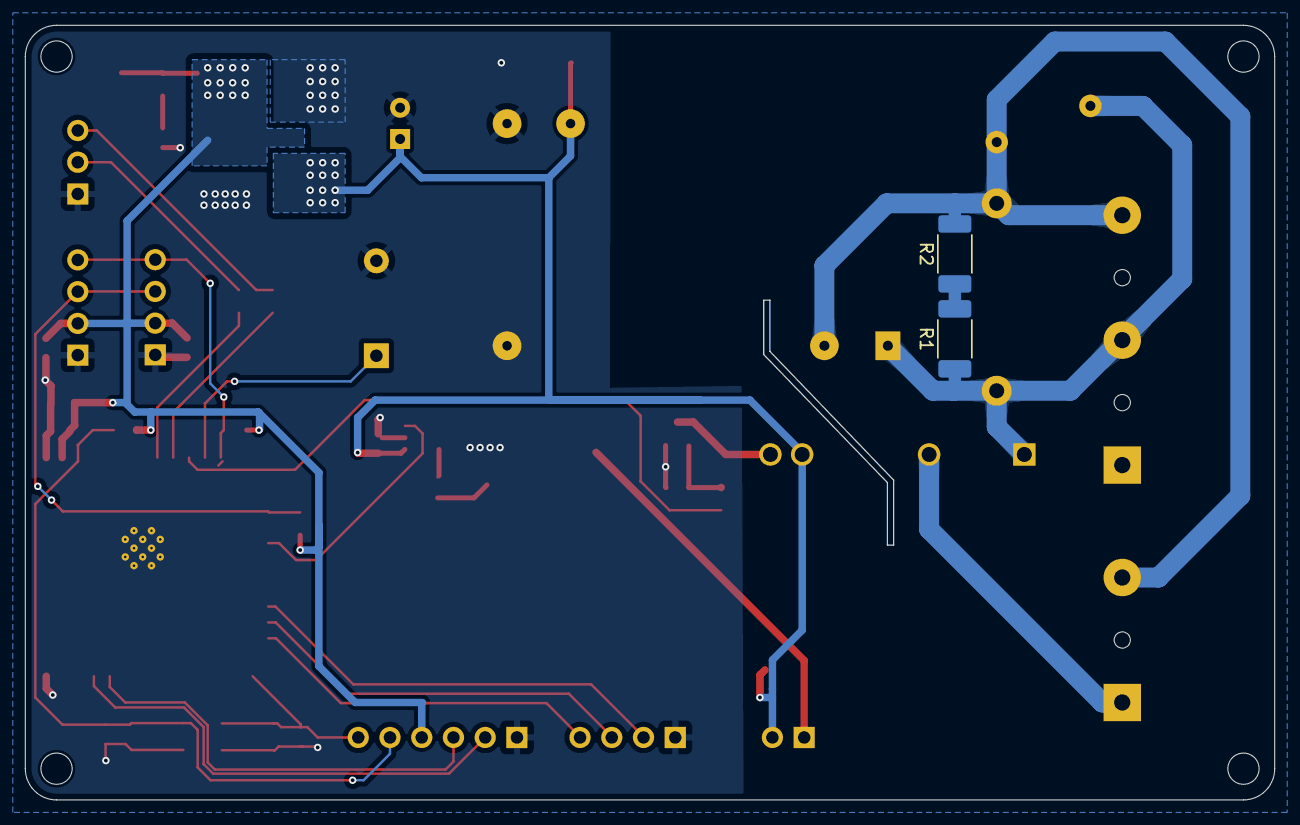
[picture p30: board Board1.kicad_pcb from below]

Board: 2 copper layers, 100.0 x 62.0 mm, 50 parts (2 on the bottom side), 29 nets.

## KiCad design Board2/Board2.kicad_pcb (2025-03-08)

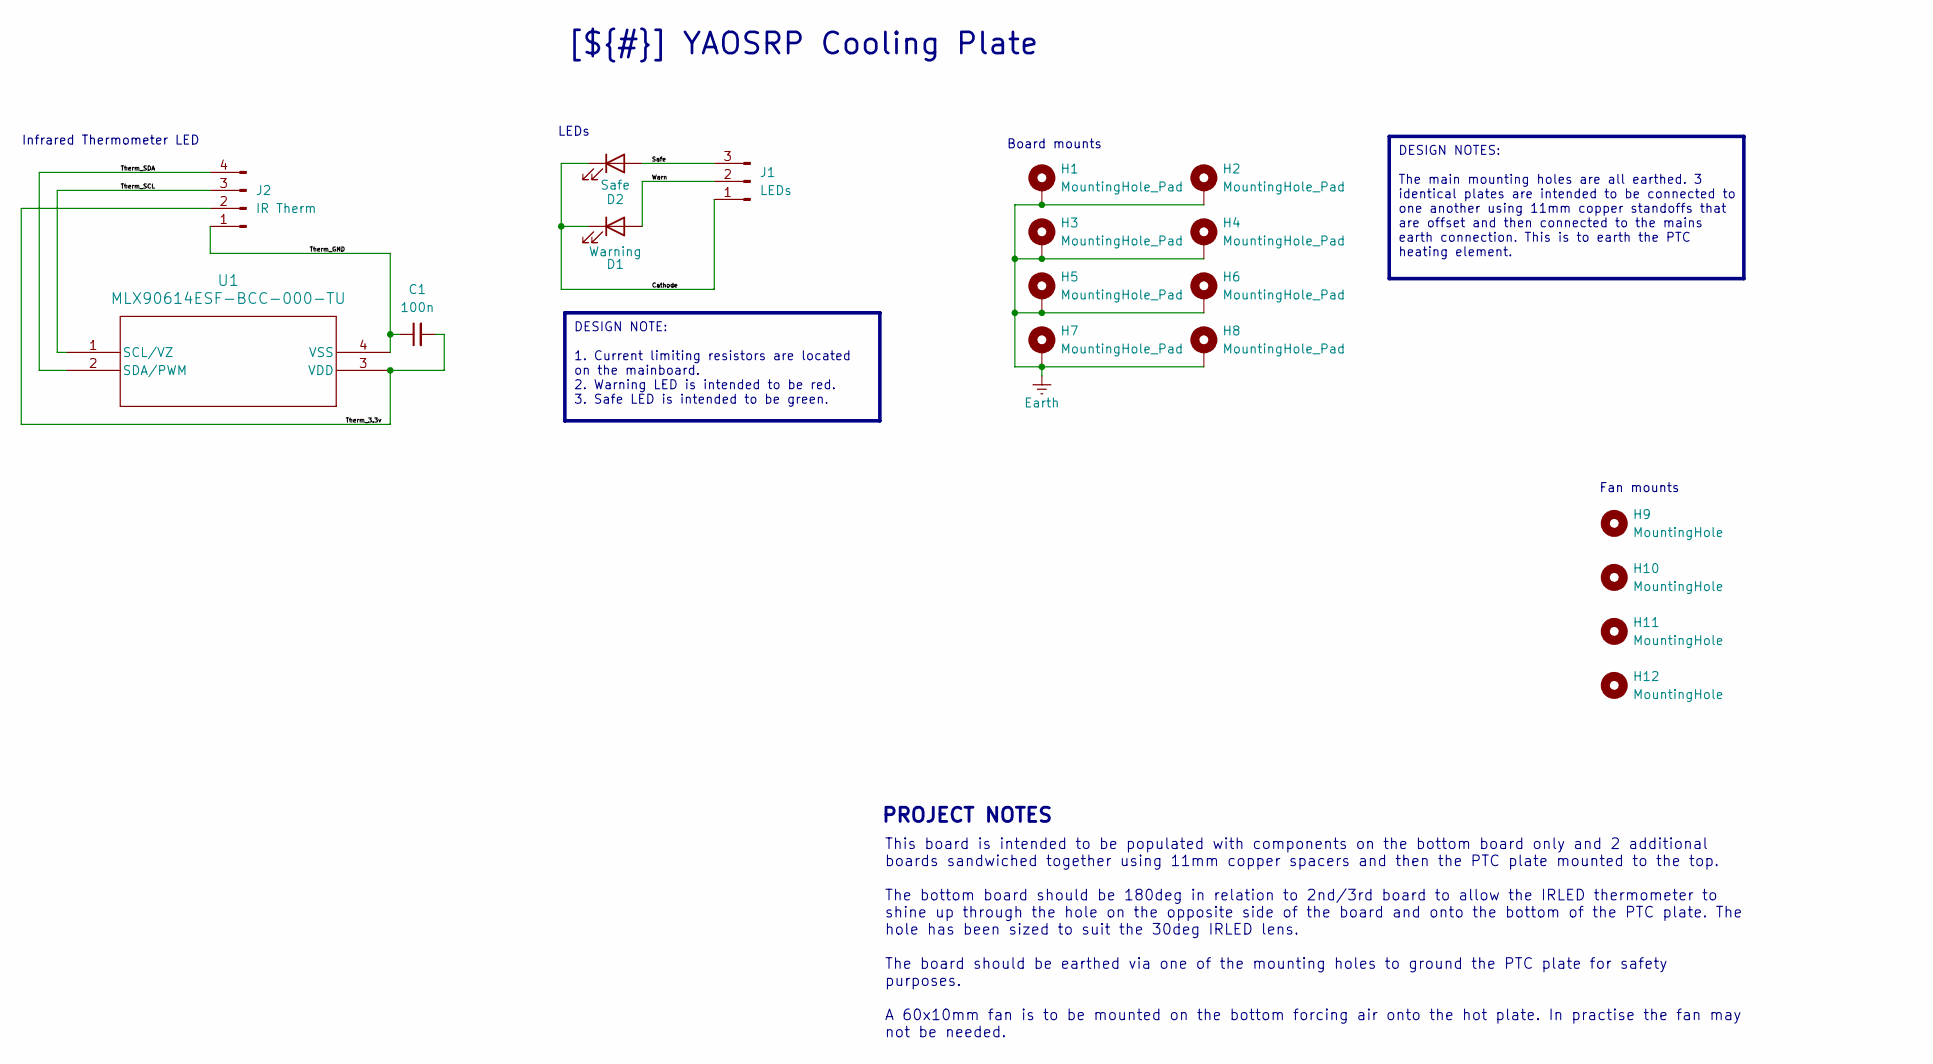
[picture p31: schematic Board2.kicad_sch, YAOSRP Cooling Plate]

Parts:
C1: 100n; C_0603_1608Metric; Digikey_PN CC0603KRX7R7BB104
D1: Warning; LED_D3.0mm
D2: Safe; LED_D3.0mm
H1, H2, H3, H4, H5, H6, H7, H8: MountingHole_Pad; MountingHole_2.5mm_Pad_TopBottom
H9, H10, H11, H12: MountingHole; MountingHole_2.5mm
J1: LEDs; PinHeader_1x03_P2.54mm_Horizontal
J2: IR Therm; PinHeader_1x04_P2.54mm_Horizontal
U1: MLX90614ESF-BCC-000-TU; IRTHERMO_MLX90614xCC_MEL; Digikey_PN MLX90614ESF-BCC-000-TU-ND

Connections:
/Cathode: D1.1 (K), D2.1 (K), J1.1
/Safe: D2.2 (A), J1.3
/Therm_3.3v: C1.2, J2.2, U1.3 (VDD)
/Therm_GND: C1.1, J2.1, U1.4 (VSS)
/Therm_SCL: J2.3, U1.1 (SCL/VZ)
/Therm_SDA: J2.4, U1.2 (SDA/PWM)
/Warn: D1.2 (A), J1.2
Earth: H1.1, H2.1, H3.1, H4.1, H5.1, H6.1, H7.1, H8.1

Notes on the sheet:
Fan mounts
LEDs
PROJECT NOTES
Board mounts
Infrared Thermometer LED
This board is intended to be populated with components on the bottom board only and 2 additional boards sandwiched together using 11mm copper spacers and then the PTC plate mounted to the top. The bottom board should be 180deg in relation to 2nd/3rd board to allow the IRLED thermometer to shine up 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
DESIGN NOTES: The main mounting holes are all earthed. 3 identical plates are intended to be connected to one another using 11mm copper standoffs that are offset and then connected to the mains earth connection. This is to earth the PTC heating element.
DESIGN NOTE: 1. Current limiting resistors are located on the mainboard. 2. Warning LED is intended to be red. 3. Safe LED is intended to be green.
[${#}] ${TITLE}

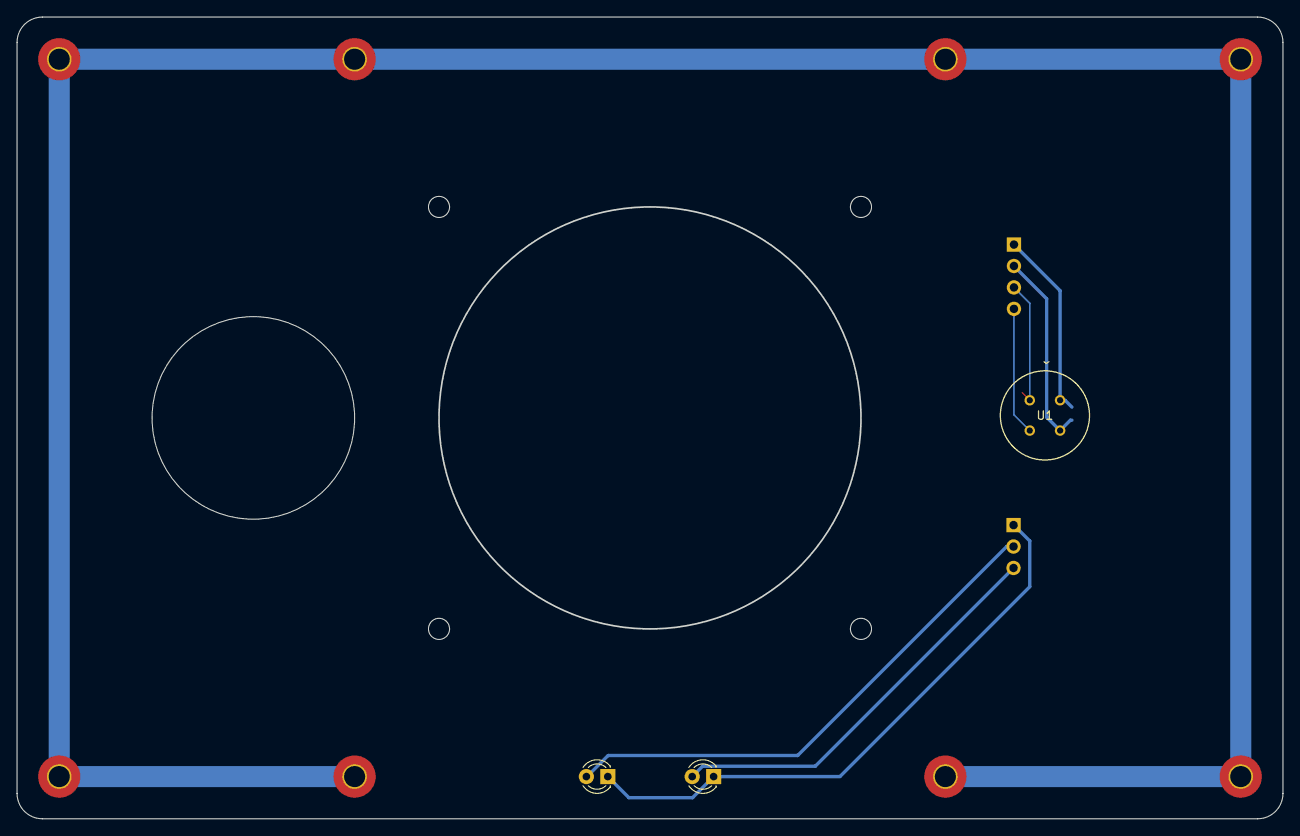
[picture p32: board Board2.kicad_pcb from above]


Board: 2 copper layers, 150.0 x 95.0 mm, 18 parts (3 on the bottom side), 8 nets.

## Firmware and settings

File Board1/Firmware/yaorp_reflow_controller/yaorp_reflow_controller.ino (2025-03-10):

/* ---================================YAORP32 v0.2 ==================================---
Software to drive Wattle Labs YAORP32 (Yet Another Open Reflow Plate) based on ESP32 S3
and commonly available aluminium 400W PTC heating plates from AliExpress. Temperature is
determined using an MLX90614 Infrared thermometer. The PTC is driven by an SSR using PWM
and controlled by a PID.

Revision History:

v0.1 - Initial release for testing and circuit board design purposes. Future improvements
may implement selectable reflow curves. For now the reflow temp can be changed in the UI and
the single curve in the code using "temp_preheat" variable.

v0.2 - Implemented and tested MLX90614 infrared thermometer. Testing shows the MLX90614
works better with the PID VS the thermocouple so the later has been removed from circuit
and firmware. MLX is more responsive to the temperature response of the PTC meaning the PID
is more accurate with far less overshoot. Physical spacing from PTC is important. Found that
with a 20mm gap between, the MLX reached 70degC. Spaced to 40mm it only reached 30degC
(ambient 25degC).

v0.3 - Added some non-blocking code to flash the warning LED when the temperature is >
80 deg C.
*/

/* --- To do ---
1. Add confirmation sound(s) when each phase completes. Maybe a pip to represent each phase
2. Add a safety timer that will shutdown the PID/Hotplate if the elapsed time exceeds a value
3. Add a safety check for thermocouple/infrared thermometer to ensure they are connected before
    allowing attempted operation.
4. Add a power bar graph to the OLED display when the SSR is running.
*/

// Native libraries
#include <Arduino.h>
#include <Wire.h>

#include "driver/ledc.h"  // ESP32 library for hardware timers (for LED flashing, and SSR PWM)

// Third party libraries
#include <U8g2lib.h>           // Graphics library for OLED screen - https://github.com/olikraus/u8g2
#include <DFRobot_MLX90614.h>  // MLX90614 Infrared Thermometer library - https://github.com/DFRobot/DFRobot_MLX90614
#include <AutoPID.h>           // PID libary - https://ryand.io/AutoPID/
#include "avdweb_Switch.h"     // Switch library for debounce and hold function - https://github.com/avdwebLibraries/avdweb_Switch
#include <Rotary.h>            // Rotary encoder library

// UI image resources
#include "logos.h"

// I2C GPIO connections for OLED display (SSD1306)
#define PIN_I2C_SDA 8
#define PIN_I2C_SCL 9

// Ancillary GPIO connections for SSR, Buzzer, indicator LEDs
#define PIN_SSR 17
#define PIN_BUZZER 18
#define PIN_FAN 11 // not used at this point
#define PIN_LED_SAFE 16
#define PIN_LED_WARN 15

// Rotary encoder GPIO connections
#define PIN_ROTARY_A 47  // rotary encoder CLK pin << reverse these two assignments if the rotation doesn't match
#define PIN_ROTARY_B 48  // rotary encoder SIG pin << (ie, clockwise should increase temp)
#define PIN_ROTARY_BUT 21  // press and hold button > 1s to "select"

// PID settings and gains
#define OUTPUT_MIN 0
#define OUTPUT_MAX 255
#define KP 2
#define KI .0025
#define KD 9

/* Try these :)
#define KP .12
#define KI .0003
#define KD 0
*/

#define TEMP_READ_DELAY 250    // Delay in ms to take temperature readings. Max6675 allows only every ~250ms
#define SCREEN_DRAW_DELAY 500  // Delay in ms to update the OLED display.
#define WARN_LED_DELAY 250     // Delay between switch states for non-blocking flashing of warning LED at high temps

// Variables /////////////////////////////////////////////////////////////////
unsigned long lastTempUpdate = 0;    //tracks time of last temp update
unsigned long lastScreenUpdate = 0;  //tracks time of last screen update
unsigned long lastTimerUpdate = 0;   // tracks timer of last timer update
unsigned long lastWarnLEDUpdate = 0;   // tracks timer of last warning LED flash update

int warnLEDState = LOW; // initial state of the warning LED for non-blocking flash

int timerMode;  // used to track how long to spend in each mode once temperature is reached by the PID

double temperature, setTemp, outputVal;
double temp_preheat = 130;
double temp_reflow = 165;
int mode;  // 0 = Idle, 1 = Preheat, 2 = Soak, 3 = Reflow
int screen;
char *modeDescription = "";

bool boolAtSetPoint = false;
/////////////////////////////////////////////////////////////////////////////

// Instansiate SSD1306 display object
U8G2_SSD1306_128X64_NONAME_F_HW_I2C u8g2(U8G2_R0, PIN_I2C_SCL, PIN_I2C_SDA, U8X8_PIN_NONE);

// Instantiate MLX90614 InfraRed thermometer object
DFRobot_MLX90614_I2C mlx(0x5A, &Wire);

// Instantiate AutoPID object
// input/output variables passed by reference, so they are updated automatically
AutoPID myPID(&temperature, &setTemp, &outputVal, OUTPUT_MIN, OUTPUT_MAX, KP, KI, KD);

// Instantiate rotary encoder rotation detection/debounce object - library "Rotary"
Rotary rotary = Rotary(PIN_ROTARY_A, PIN_ROTARY_B);

// Instantiate rotary encoder switch debounce object - library "AVDWeb_Switch"
//Switch pushButton = Switch(PIN_ROTARY_BUT, INPUT_PULLUP, LOW, 1);
Switch pushButton = Switch(PIN_ROTARY_BUT, INPUT, LOW);

void setup() {
  Serial.begin(115200);
  Serial.println(F("Debug started..."));

  // Setup ledc channels for PWM control of SSR and sound output
  // Note the channel set-up was required to ensure SSR PWM freq. = 1kHz.
  ledcAttachChannel(PIN_SSR, /*PWM_FREQUENCY*/ 1000, /*PWM_RESOUTION */ 8, /*CHANNEL*/ 7);  // 1000Hz needed to drive the plate to full temperatures!
  ledcAttachChannel(PIN_BUZZER, /*PWM_FREQUENCY=*/1000, /*PWM_RESOUTION=*/8, /*CHANNEL*/ 0);

  // Setup temperature warning and safe temperature LEDs
  pinMode(PIN_LED_SAFE, OUTPUT);
  pinMode(PIN_LED_WARN, OUTPUT);

  // Initialize I2C to 100kHz suitable for the IR thermometer
  Wire.setClock(100000);

  // Setup PID
  myPID.setBangBang(30);               // Bang bang set to > 30 below setpoint (0 to turn off)
  myPID.setTimeStep(TEMP_READ_DELAY);  // set PID update freq. to same as temperature sensor

  // Ensure status LEDs reflect startup temperature!
  getTemperature();

  updateLEDs();  // Update LEDs based on plate temperature

  ui_boot();  // Display boot screen

  disableSSR();  // Ensure the SSR is turned off at boot

  mode = 0;    // Start in idle mode
  screen = 0;  // Start in temp monitoring screen
}

void loop() {
  processEncoder();  // Process the rotary encoder

  getTemperature();  // Get temperature from thermocouple/IR thermometer

  updateLEDs();  // Update LEDs based on plate temperature

  updateUI();  // Update OLED display

  processModes();  // Pre-heat, soak, reflow...
}

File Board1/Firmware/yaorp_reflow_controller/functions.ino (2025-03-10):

//call repeatedly in loop, only updates after a certain time interval
//returns true if update happened
bool getTemperature() {
  if ((millis() - lastTempUpdate) > TEMP_READ_DELAY) {
    temperature = mlx.getObjectTempCelsius();

    lastTempUpdate = millis();
    return true;
  }
  return false;
}

void updateTimer() {
  if ((millis() - lastTimerUpdate) > 1000) {
    if (timerMode > 0) {
      timerMode = timerMode - 1;
      lastTimerUpdate = millis();
      Serial.println(timerMode);
    }
  }
}

// Status LEDs
void updateLEDs() {
  unsigned long currentMillis = millis();

  if (temperature > 40 && temperature < 80) {
    digitalWrite(PIN_LED_WARN, HIGH);
    digitalWrite(PIN_LED_SAFE, LOW);
  } else if (temperature > 80) {
    if (currentMillis - lastWarnLEDUpdate >= 250) {
      lastWarnLEDUpdate = currentMillis;

      if (warnLEDState == LOW) {
        warnLEDState = HIGH;
      } else {
        warnLEDState = LOW;
      }
      digitalWrite(PIN_LED_WARN, warnLEDState);
      digitalWrite(PIN_LED_SAFE, LOW);
    }

  } else {
    digitalWrite(PIN_LED_WARN, LOW);
    digitalWrite(PIN_LED_SAFE, HIGH);
  }
}

void disableSSR() {
  setTemp = 0;
  ledc_stop(LEDC_LOW_SPEED_MODE, LEDC_CHANNEL_7, 0);
}

void updateSSR(double PWM) {
  ledcWrite(PIN_SSR, PWM);
}

void processModes() {
  // Idle
  if (mode == 0) {  // Idle mode
    disableSSR();
    timerMode = 0;
    modeDescription = "Idle";
  }

  // Preheat to soak
  if (mode == 1) {
    modeDescription = "Preheat";
    setTemp = temp_preheat;

    myPID.run();

    updateSSR(outputVal);

    if (myPID.atSetPoint(2)) {
      timerMode = 90;  // start countdown timer 90s
      mode = 2;        // Soak mode
    }
  }

  // Soak
  if (mode == 2) {
    modeDescription = "Soak";

    myPID.run();

    updateSSR(outputVal);

    if (myPID.atSetPoint(2)) {
      boolAtSetPoint = true;  // only start the timer if we reached the setpoint
    }

    if (boolAtSetPoint) {
      updateTimer();
    }

    // Soak countdown timer is complete, move to reflow
    if (timerMode == 0) {
      timerMode = 20;  // start
      mode = 3;        // Reflow mode
      boolAtSetPoint = false;
    }
  }

  // Reflow
  if (mode == 3) {
    modeDescription = "Reflow";
    setTemp = temp_reflow;

    myPID.run();

    updateSSR(outputVal);

    if (myPID.atSetPoint(2)) {
      boolAtSetPoint = true;  // only start the timer if we reached the setpoint
    }

    if (boolAtSetPoint) {
      updateTimer();
    }

    if (timerMode == 0) {  // reflow is finished, revert to idle mode
      mode = 0;
      screen = 0;
      boolAtSetPoint = false;
    }
  }
}

void processEncoder() {
  // Poll rotary encoder and pushbutton /////////////////////////////////////////
  unsigned char result = rotary.process();
  pushButton.poll();

  // process rotary encoder inputs only when in the temperature select screen ///
  if (screen == 1 && result == DIR_CW && (temp_reflow < 220)) {
    temp_reflow += 5;
    soundClick();
  }

  if (screen == 1 && result == DIR_CCW && (temp_reflow > 160)) {
    temp_reflow -= 5;
    soundClick();
  }

  // Process long press as appropriate
  if (pushButton.longPress()) {
    if (screen == 0) {
      screen = 1;
      soundConfirm();
    } else if (screen == 1) {
      screen = 2;
      mode = 1;
      soundConfirm();
    } else if (screen == 2) {
      screen = 0;
      mode = 0;
      soundCancel();
    }
  }
}

void updateUI() {
  if ((millis() - lastScreenUpdate) > SCREEN_DRAW_DELAY) {

    if (screen == 0) {
      ui_idle(temperature);
    }

    if (screen == 1) {
      ui_temp();
    }

    if (screen == 2) {
      ui_heating(modeDescription, setTemp, temperature, timerMode);
    }

    lastScreenUpdate = millis();
  }
}

void soundBoot() {
  // Play startup sound
  ledcWriteTone(PIN_BUZZER, 1000);
  delay(250);
  ledcWriteTone(PIN_BUZZER, 1800);
  delay(180);
  ledcWriteTone(PIN_BUZZER, 0);
}

void soundCancel() {
  // Play cancel sound
  ledcWriteTone(PIN_BUZZER, 1800);
  delay(300);
  ledcWriteTone(PIN_BUZZER, 0);
  delay(50);
  ledcWriteTone(PIN_BUZZER, 1400);
  delay(300);
  ledcWriteTone(PIN_BUZZER, 0);
  delay(50);
  ledcWriteTone(PIN_BUZZER, 1000);
  delay(100);
  ledcWriteTone(PIN_BUZZER, 0);
}

void soundConfirm() {
  ledcWriteTone(PIN_BUZZER, 1800);
  delay(75);
  ledcWriteTone(PIN_BUZZER, 0);
  delay(50);
  ledcWriteTone(PIN_BUZZER, 1800);
  delay(75);
  ledcWriteTone(PIN_BUZZER, 0);
}

void soundClick() {
  ledcWriteTone(PIN_BUZZER, 1800);
  delay(3);
  ledcWriteTone(PIN_BUZZER, 0);
}

void ui_boot() {
  // Render boot screen and play "on" tone from piezo
  u8g2.setBusClock(100000);
  u8g2.begin();
  u8g2.enableUTF8Print();

  u8g2.clearBuffer();
  u8g2.setFontMode(1);
  u8g2.setBitmapMode(1);

  u8g2.drawXBMP(12, 0, 37, 64, icon_logo);

  u8g2.setFont(u8g2_font_helvB08_tr);
  u8g2.drawStr(54, 26, "Wattle Labs");
  u8g2.drawStr(57, 41, "YAORP32");

  u8g2.sendBuffer();
  soundBoot();

  delay(2000);
}

void ui_idle(int temp) {
  // Render idle screen showing current plate temperature
  // screen = 1

  char buffer[4] = "";

  u8g2.clearBuffer();
  u8g2.setFontMode(1);
  u8g2.setBitmapMode(1);

  u8g2.setFont(u8g2_font_helvB08_tr);
  u8g2.drawStr(55, 10, "Idle");

  u8g2.drawXBMP(34, 24, 16, 16, icon_temperature);

  itoa(temp, buffer, 10);  // convert int to string

  u8g2.setFont(u8g2_font_profont22_tr);
  u8g2.drawStr(60, 39, buffer);

  u8g2.setFont(u8g2_font_5x8_tr);
  u8g2.drawStr(14, 64, "Hold Select to Start");

  u8g2.sendBuffer();
}

void ui_temp() {
  // Render temperature selection screen
  // screen = 2
  char buffer[4] = "";

  u8g2.clearBuffer();
  u8g2.setFontMode(1);
  u8g2.setBitmapMode(1);

  u8g2.setFont(u8g2_font_helvB08_tr);
  u8g2.drawStr(13, 8, "Select Reflow Temp:");

  u8g2.drawXBMP(34, 24, 16, 16, icon_temperature);

  itoa(temp_reflow, buffer, 10);  // convert int to string

  u8g2.setFont(u8g2_font_profont22_tr);
  u8g2.drawStr(60, 39, buffer);

  u8g2.setFont(u8g2_font_5x8_tr);
  u8g2.drawStr(14, 64, "Hold Select to Start");

  u8g2.sendBuffer();
}

void ui_heating(char *phase, int temp_target, int temp_current, int timer) {
  // Render heating screen showing current phase
  // screen = 3
  char buffer[4] = "";

  u8g2.clearBuffer();
  u8g2.setFontMode(1);
  u8g2.setBitmapMode(1);

  u8g2.setFont(u8g2_font_5x8_tr);
  u8g2.drawStr(12, 64, "Hold Select to Cancel");

  u8g2.drawXBMP(34, 24, 16, 16, icon_temperature);

  itoa(temp_target, buffer, 10);  // convert int to string
  u8g2.setFont(u8g2_font_helvB08_tr);
  u8g2.drawStr(100, 8, "T:");
  u8g2.drawStr(110, 8, buffer);

  if (timer > 0) {            // only display a timer if one is active
    itoa(timer, buffer, 10);  // convert int to string
    u8g2.drawStr(58, 8, buffer);
  }

  u8g2.setFont(u8g2_font_helvB08_tr);
  u8g2.drawStr(0, 8, phase);

  itoa(temp_current, buffer, 10);  // convert int to string
  u8g2.setFont(u8g2_font_profont22_tr);
  u8g2.drawStr(60, 39, buffer);

  u8g2.sendBuffer();
}

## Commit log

2025-02-20 Resolve library and ERC issues
    No changes to design.
    [Board1.kicad_pcb, Board2.kicad_pcb, Board2.kicad_sch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]
2025-03-08 v1.2 release of board with bug fixes etc
    [Board1.kicad_pcb, Board1.kicad_sch, Board2.kicad_pcb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]
2025-03-10 Tweaks to schematic for clarity and minor firmware
    [Board1.kicad_pcb, Board1.kicad_sch, project history.kicad_sch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]
